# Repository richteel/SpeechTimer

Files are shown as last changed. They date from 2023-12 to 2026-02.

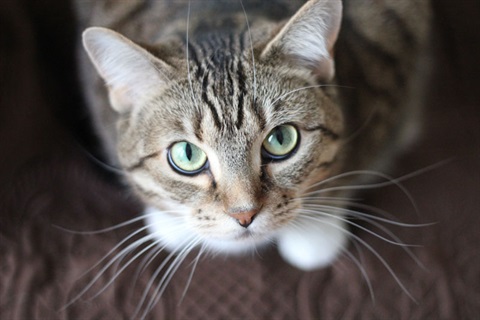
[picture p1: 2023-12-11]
CircuitPython/wwwroot/images/cat.jpg

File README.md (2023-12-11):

# SpeechTimer
Clock/Timer for Speeches

# Folder Structure #

There are several folders in this project. Below is a brief description of each one.

- **CircuitPython:** An early prototype with a web interface. It works but is unstable due to memory fragmentation. It is no longer being developed. It is kept here if anyone using Python wants to use it or improve upon it.
- **Documentation:** Some documentation used during development along with user guide and other miscellaneous materials.
	- **Speech Timer - Developer Guide.docx:** Not much here at the moment. *(Just a placeholder)*
	- **Speech Timer - User Guide.docx:** Very basic user guide showing how to use the remote.
- **PCB:** Eagle project with schematic and PCB design. This is for the development version, which incorporates two Raspberry Pi Pico boards. A regular Raspberry Pi Pico as a Picoprobe and a Raspberry Pi Pico W as the micro-controller running the show.
- **SD Card:** Contents for the micro SD card.
- **SpeechTimer:** The Arduino Sketch C++ project written using the Arduino IDE. Currently everything seems to be working, but the Web Interface has not been created yet.

# Parts List #

- Raspberry Pi Pico
	- Quantity: 1
	- Note: Used as Picoprobe for programming and debugging
- Raspberry Pi Pico W
	- Quantity: 1
- 5mm Neopixels (Through hole)
	- Quantity: 58
	- Source(s): [Adafruit](https://www.adafruit.com/product/1938) / [AliExpress](https://www.aliexpress.us/item/3256804752897372.html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)
- SD Card Breakout
	- Quantity: 1
	- Source(s): [Adafruit](https://www.adafruit.com/product/4682)
- Monochrome 0.96" 128x54 OLED Display
	- Quantity: 1
	- Source(s): [Adafruit](https://www.adafruit.com/product/326) / [Amazon](https://www.amazon.com/gp/product/B08VNRH5HR/ref=ppx_yo_dt_b_search_asin_image?ie=UTF8&th=1)
- Remote
	- Quantity: 1
	- Source(s): [Amazon](https://www.amazon.com/gp/product/B0C7BPJYH1/ref=ppx_yo_dt_b_search_asin_image?ie=UTF8&psc=1)
- 2.54mm (0.1") JST Connectors (3, 4, & 6 position)
	- Quantity: 1 each 3-position, 4-position, and 6-position
	- Source(s): [Amazon](https://www.amazon.com/gp/product/B015Y6JOUG/ref=ppx_yo_dt_b_search_asin_image?ie=UTF8&psc=1) / [AliExpress](https://www.aliexpress.us/item/2251832778234720.html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)
- 2.54mm (0.1") Female Headers
	- Quantity: 5 (4 20-position, 1 9-position)
	- Source(s): [Adafruit](https://www.adafruit.com/product/598)
- 2.54mm (0.1") Male Headers
	- Quantity: 5 (4 20-position, 1 9-position)
	- Source(s): [Adafruit](https://www.adafruit.com/product/2671)
- Momentary Push Button Switch (N.O.) 6mm slim
	- Quantity: 2
	- Source(s): [Adafruit](https://www.adafruit.com/product/1489)
- IR Receiver TSOP38238
	- Quantity: 1
	- Source(s): [Adafruit](https://www.adafruit.com/product/157) / [AliExpress](https://www.aliexpress.us/item/2251832658861424.html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)
- IR LED 5mm
	- Quantity: 1
	- Source(s): [Adafruit](https://www.adafruit.com/product/388)
- Red LED 3mm
	- Quantity: 1
	- Source(s): [Adafruit](https://www.adafruit.com/product/777)
- CdS Photoresistor
	- Quantity: 1
	- Source(s): [Adafruit](https://www.adafruit.com/product/161)

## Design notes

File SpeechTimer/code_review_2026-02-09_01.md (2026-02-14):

# Code Review - SpeechTimer Project
**Date:** February 9, 2026  
**Reviewer:** GitHub Copilot  
**Platform:** Raspberry Pi Pico W  

---

## **Overall Architecture** ✅

### Strengths:
- Well-organized modular structure with clear separation of concerns (Clk_Output, Clk_Rtc, Clk_Wifi, Clk_SdCard, Clk_Remote)
- Good use of FreeRTOS tasks for concurrent operations
- Appropriate use of queues for inter-task communication

### Concerns:
- Tight coupling between classes through direct pointer passing in constructors
- Global objects could make testing and reusability difficult

---

## **Memory & Resource Management** ⚠️

### Critical Issues:

#### 1. Buffer Overflows in `config.h`
**Location:** Lines 1-26  
**Issue:** Excessively large buffer allocations
- `char ssid[256]` and `char pass[256]` are too large for embedded systems
- `char hostname[256]` is also oversized
- These consume 768 bytes per NetworkInfo struct

**Recommendation:**
```cpp
struct NetworkInfo {
  char ssid[32];   // Changed from 256
  char pass[64];   // Changed from 256
};

struct Config {
  char hostname[32];  // Changed from 256
  char timezone[64];  // Changed from 256
  NetworkInfo networks[NETWORKINFOARRAYSIZE];
  TimerInfo timers[TIMERARRAYSIZE];
};
```

#### 2. String Buffer Risks in `Clk_Rtc.cpp`
**Location:** Line 84  
**Issue:** Unbounded stack allocation
```cpp
char responseBuffer[charCount + 1];  // Could overflow stack
```

**Recommendation:**
```cpp
constexpr size_t MAX_RESPONSE_SIZE = 2048;
if (charCount > MAX_RESPONSE_SIZE) {
    charCount = MAX_RESPONSE_SIZE;
}
char responseBuffer[MAX_RESPONSE_SIZE];
int c = _clock_Wifi->wifiClient.read(responseBuffer, charCount);
```

#### 3. Memory Leaks Potential in `Clk_Rtc.cpp`
**Location:** Lines 186-203 (deserializeInternetTime)  
**Issue:** Storing raw pointers to temporary JSON document data
```cpp
_lastInternetTime.abbreviation = doc["abbreviation"];  // Dangling pointer!
_lastInternetTime.client_ip = doc["client_ip"];
```

**Recommendation:** Change `InternetTimeStruct` to store actual strings:
```cpp
struct InternetTimeStruct {
  char abbreviation[8];        // Changed from const char*
  char client_ip[16];          // Changed from const char*
  char datetime[64];           // Changed from const char*
  int day_of_week;
  int day_of_year;
  bool dst;
  char dst_from[64];           // Changed from const char*
  int dst_offset;
  char dst_until[64];          // Changed from const char*
  int raw_offset;
  char timezone[64];           // Changed from const char*
  long unixtime;
  char utc_datetime[64];       // Changed from const char*
  char utc_offset[8];          // Changed from const char*
  int week_number;
};
```

Then use `strlcpy()` in deserializeInternetTime:
```cpp
strlcpy(_lastInternetTime.abbreviation, doc["abbreviation"] | "", 
        sizeof(_lastInternetTime.abbreviation));
```

---

## **Concurrency & Thread Safety** ⚠️

### Issues:

#### 1. Inconsistent Mutex Usage in `SpeechTimer.ino`
**Issue:** `rtc_mutex` is created but never used

**Locations where RTC is accessed without protection:**
- Line 210: `clockRtc.getTimeString(timeStr)` in `debugMessage()`
- Line 366: `clockRtc.getTimeString(currentTime)` in `checkWiFi()`
- Line 405: `clockRtc.getTimeString(currentTime)` in `clockUpdate()`

**Recommendation:**
```cpp
void debugMessage(const char *message, const char *logfile = "", 
                  DebugLevels debug_level = DebugLevels::Info) {
  const char *errorlevel = debugLevelName[debug_level];
  if (debug_level < debugLevel) {
    return;
  }

  char timeStr[10] = "--:--";
  
  // Protect RTC access
  if (xSemaphoreTake(rtc_mutex, pdMS_TO_TICKS(100)) == pdTRUE) {
    clockRtc.getTimeString(timeStr);
    xSemaphoreGive(rtc_mutex);
  }
  
  char msgBuffer[512];
  sprintf(msgBuffer, "%s\t%s\t%s %s\t%d\t%d\t%d", timeStr, errorlevel, 
          FILE_NAME, message, xPortGetCoreID(), rp2040.getFreeHeap(), 
          uxTaskGetStackHighWaterMark(NULL));
  // ... rest of function
}
```

#### 2. Race Conditions
**Issue:** Shared variables accessed without synchronization

**Vulnerable Variables:**
- `configLoadMillis` and `last_configLoadMillis` (lines 149, 337-346)
- `last_clockMode` (line 161, 467-471)
- `last_ipaddress` (line 144, 349-355)
- `last_WiFiMode` (line 145, 358-362)

**Recommendation:** Create additional mutexes or use atomic operations:
```cpp
static SemaphoreHandle_t config_mutex;
static SemaphoreHandle_t display_mutex;

// In setup():
config_mutex = xSemaphoreCreateMutex();
display_mutex = xSemaphoreCreateMutex();

// When accessing:
if (xSemaphoreTake(config_mutex, pdMS_TO_TICKS(100)) == pdTRUE) {
    if (configLoadMillis != last_configLoadMillis) {
        // ... handle config change
    }
    xSemaphoreGive(config_mutex);
}
```

#### 3. Deadlock Risk in `checkSdCard` Task
**Location:** Lines 269-275  
**Issue:** Doesn't handle mutex acquisition failure gracefully

**Current Code:**
```cpp
if (xSemaphoreTake(sdcard_mutex, 100) == pdTRUE) {
    clockSdCard.writeLogEntry(item.logfile, item.message);
    xSemaphoreGive(sdcard_mutex);
} else {
    Dbg_printf(...);  // Just prints error
    writeToFile = false;
}
```

**Recommendation:** Add retry logic or re-queue the item:
```cpp
const uint8_t MAX_RETRIES = 3;
uint8_t retries = 0;

while (retries < MAX_RETRIES) {
    if (xSemaphoreTake(sdcard_mutex, pdMS_TO_TICKS(100)) == pdTRUE) {
        clockSdCard.writeLogEntry(item.logfile, item.message);
        xSemaphoreGive(sdcard_mutex);
        break;
    }
    retries++;
    vTaskDelay(pdMS_TO_TICKS(50));  // Brief delay before retry
}

if (retries >= MAX_RETRIES) {
    // Re-queue or log failure
    xQueueSendToFront(log_queue, &item, 0);  // Try to preserve message
}
```

---

## **Error Handling** ⚠️

### Issues:

#### 1. Silent Failures in `Clk_Wifi.cpp`
**Location:** Line 76  
**Issue:** `checkConnection()` is empty

```cpp
void Clk_Wifi::checkConnection(int maxRetries, bool fromBegin) {
    // Empty function!
}
```

**Recommendation:** Implement proper connection checking:
```cpp
void Clk_Wifi::checkConnection(int maxRetries, bool fromBegin) {
    if (wifiMode != WIFI_STA) {
        return;  // Only check in station mode
    }
    
    for (int i = 0; i < maxRetries; i++) {
        if (WiFi.status() == WL_CONNECTED) {
            return;
        }
        
        DEBUGV("%s checkConnection - Retry %d/%d\n", 
               FILE_NAME_WIFI, i + 1, maxRetries);
        
        if (wifiMulti.run() == WL_CONNECTED) {
            return;
        }
        
        delay(1000);
    }
    
    // Failed to connect
    DEBUGV("%s checkConnection - Failed after %d retries\n", 
           FILE_NAME_WIFI, maxRetries);
}
```

#### 2. Stack Overflow Risk in `Clk_Wifi.cpp`
**Location:** Lines 54-62  
**Issue:** Recursive call to `begin()` could overflow stack

**Current Code:**
```cpp
if (wifiMulti.run() != WL_CONNECTED) {
    if (_beginLoopCount < 5) {
        DEBUGV(...);
        _beginLoopCount++;
        delay(1000);
        begin(configuration);  // Recursive!
```

**Recommendation:** Use iteration instead:
```cpp
bool Clk_Wifi::begin(Config *configuration) {
    config = configuration;
    apAddedCount = 0;
    _beginLoopCount = 0;
    
    // ... setup code ...
    
    // Replace recursion with loop
    const uint8_t MAX_ATTEMPTS = 5;
    while (_beginLoopCount < MAX_ATTEMPTS) {
        if (wifiMulti.run() == WL_CONNECTED) {
            DEBUGV("%s begin - WiFi connected, SSID: %s\n", 
                   FILE_NAME_WIFI, WiFi.SSID().c_str());
            DEBUGV("%s begin - IP address: %s\n", 
                   FILE_NAME_WIFI, WiFi.localIP().toString().c_str());
            return true;
        }
        
        _beginLoopCount++;
        DEBUGV("%s begin - Attempt %d/%d failed\n", 
               FILE_NAME_WIFI, _beginLoopCount, MAX_ATTEMPTS);
        delay(1000);
    }
    
    DEBUGV("%s begin - Failed to connect after %d attempts\n", 
           FILE_NAME_WIFI, MAX_ATTEMPTS);
    return false;
}
```

#### 3. No Timeout Handling in `Clk_Rtc.cpp`
**Location:** Lines 27-47  
**Issue:** Connection could hang despite timeout parameter

**Recommendation:** Add connection timeout:
```cpp
long Clk_Rtc::getInternetTime(long timeoutMs) {
    // ... setup code ...
    
    unsigned long connectStart = millis();
    while (!_clock_Wifi->wifiClient.connect(server, 80)) {
        if (millis() - connectStart > timeoutMs / 2) {
            DEBUGV("[CLK_RTC] Connection timeout\n");
            return 0;
        }
        delay(100);
    }
    
    // ... rest of function ...
}
```

#### 4. Queue Overflow in `SpeechTimer.ino`
**Location:** Line 217  
**Issue:** When log queue is full, message is lost

**Recommendation:** Implement overflow handling:
```cpp
if (xQueueSend(log_queue, (void *)&logEntry, 10) != pdTRUE) {
    // Try to make room by dropping oldest entry
    Log_Entry dummy;
    xQueueReceive(log_queue, &dummy, 0);  // Remove oldest
    
    // Try again
    if (xQueueSend(log_queue, (void *)&logEntry, 0) != pdTRUE) {
        // Still failed, print directly
        Dbg_printf("%s: CRITICAL - Log Queue Full, message lost:\n%s\n", 
                   debugLevelName[DebugLevels::Error], msgBuffer);
    }
}
```

---

## **Code Quality** 📝

### Good Practices:
- Consistent naming conventions
- Helpful comments and documentation
- Good pin documentation in headers
- Clear file structure

### Areas for Improvement:

#### 1. Magic Numbers
**Issue:** Hardcoded values throughout code

**Examples:**
- Stack sizes: `2048` (lines 546-549)
- Delays: `250`, `100`, `10` (throughout)
- Buffer sizes: Various locations

**Recommendation:** Define constants:
```cpp
// Add to Defines.h or new Constants.h
namespace TaskConfig {
    constexpr size_t STACK_SIZE = 2048;
    constexpr TickType_t REMOTE_CHECK_DELAY_MS = 250;
    constexpr TickType_t SDCARD_CHECK_DELAY_MS = 250;
    constexpr TickType_t WIFI_CHECK_DELAY_MS = 250;
    constexpr TickType_t CLOCK_UPDATE_DELAY_MS = 100;
    constexpr uint8_t SETUP_WAIT_DELAY_MS = 10;
}

namespace QueueConfig {
    constexpr uint8_t LOG_QUEUE_LENGTH = 10;
    constexpr uint8_t REMOTE_QUEUE_LENGTH = 5;
}

namespace TimeoutConfig {
    constexpr TickType_t MUTEX_TIMEOUT_MS = 100;
    constexpr TickType_t QUEUE_SEND_TIMEOUT_MS = 10;
    constexpr long INTERNET_TIME_TIMEOUT_MS = 2000;
}
```

#### 2. Deep Nesting in `SpeechTimer.ino`
**Location:** Lines 421-480 (clockUpdate task)  
**Issue:** Complex switch statement with nested logic

**Recommendation:** Extract to state handler functions:
```cpp
void handleTimerDigitInput(char digit) {
    char numberBuffer[10];
    if (clockOutput.clockMode == ClockMode::TimerSetMin) {
        int minVal = clockOutput.timerSetMin();
        sprintf(numberBuffer, "%d%c", minVal, digit);
        minVal = atoi(numberBuffer);
        clockOutput.timerSetMin(minVal);
    } else if (clockOutput.clockMode == ClockMode::TimerSetMax) {
        int maxVal = clockOutput.timerSetMax();
        sprintf(numberBuffer, "%d%c", maxVal, digit);
        maxVal = atoi(numberBuffer);
        clockOutput.timerSetMax(maxVal);
    }
}

void handleNavigationInput(char direction) {
    if (direction == 'L' && clockOutput.clockMode == ClockMode::TimerSetMax) {
        clockOutput.clockMode = ClockMode::TimerSetMin;
    } else if (direction == 'R' && clockOutput.clockMode == ClockMode::TimerSetMin) {
        clockOutput.clockMode = ClockMode::TimerSetMax;
    }
}

void handleOkButton() {
    switch (clockOutput.clockMode) {
        case ClockMode::TimerReady:
            clockOutput.clockMode = ClockMode::TimerRun;
            break;
        case ClockMode::TimerRun:
            clockOutput.clockMode = ClockMode::TimerStop;
            break;
        case ClockMode::TimerStop:
            clockOutput.clockMode = ClockMode::TimerReady;
            break;
    }
}

// Then in clockUpdate:
while (xQueueReceive(remote_queue, (void *)&item, 0) == pdTRUE) {
    if (item >= '0' && item <= '9') {
        handleTimerDigitInput(item);
    } else if (item == 'L' || item == 'R') {
        handleNavigationInput(item);
    } else if (item == 'K') {
        handleOkButton();
    } else if (item == '*') {
        clockOutput.clockMode = ClockMode::Clock;
    } else if (item == '#') {
        handleHashButton();
    }
}
```

#### 3. Debug Macros in `DbgPrint.h`
**Location:** Lines 1-32  
**Current Implementation:** Good, but could be cleaner

**Recommendation:** Single abstraction layer:
```cpp
#ifndef DBGPRINT
#define DBGPRINT

#define DEBUG 1          // SET TO 0 TO REMOVE TRACES
#define USE_PICOPROBE 1  // Set to 1 if using Picoprobe

#if DEBUG
    #if USE_PICOPROBE
        #define DEBUG_SERIAL Serial1
    #else
        #define DEBUG_SERIAL Serial
    #endif
    
    #define Dbg_begin(...) DEBUG_SERIAL.begin(__VA_ARGS__)
    #define Dbg_end(...) DEBUG_SERIAL.end(__VA_ARGS__)
    #define Dbg_print(...) DEBUG_SERIAL.print(__VA_ARGS__)
    #define Dbg_println(...) DEBUG_SERIAL.println(__VA_ARGS__)
    #define Dbg_printf(...) DEBUG_SERIAL.printf(__VA_ARGS__)
    #define Dbg_write(...) DEBUG_SERIAL.write(__VA_ARGS__)
#else
    #define Dbg_begin(...)
    #define Dbg_end(...)
    #define Dbg_print(...)
    #define Dbg_println(...)
    #define Dbg_printf(...)
    #define Dbg_write(...)
#endif

#endif  // DBGPRINT
```

#### 4. Long Functions
**Issue:** Several functions exceed 50 lines

**Functions to refactor:**
- `getInternetTime()` in Clk_Rtc.cpp (116 lines)
- `checkSdCard()` in SpeechTimer.ino (61 lines)
- `checkWiFi()` in SpeechTimer.ino (71 lines)
- `clockUpdate()` in SpeechTimer.ino (97 lines)

**Recommendation:** Apply Single Responsibility Principle—each function should do one thing.

---

## **Potential Bugs** 🐛

### 1. Reference Bug in `Clk_SdCard.cpp`
**Location:** Line 38  
**Severity:** HIGH - Data not being cleared

**Current Code:**
```cpp
void Clk_SdCard::clearConfig() {
  sdCardConfig.hostname[0] = '\0';
  sdCardConfig.timezone[0] = '\0';

  for (NetworkInfo ni : sdCardConfig.networks) {  // BUG: Copies by value!
    ni.ssid[0] = '\0';  // Modifies copy, not original
    ni.pass[0] = '\0';
  }

  for (TimerInfo ti : sdCardConfig.timers) {  // BUG: Copies by value!
    ti.min = 0;
    ti.max = 0;
    ti.manual = true;
  }
}
```

**Fix:** Use references:
```cpp
void Clk_SdCard::clearConfig() {
  sdCardConfig.hostname[0] = '\0';
  sdCardConfig.timezone[0] = '\0';

  for (NetworkInfo& ni : sdCardConfig.networks) {  // Fixed: Use reference
    ni.ssid[0] = '\0';
    ni.pass[0] = '\0';
  }

  for (TimerInfo& ti : sdCardConfig.timers) {  // Fixed: Use reference
    ti.min = 0;
    ti.max = 0;
    ti.manual = true;
  }
}
```

### 2. Dangling Pointers in `Clk_Rtc.cpp`
**Location:** Lines 186-203  
**Severity:** CRITICAL - Will cause crashes

**Issue:** `_lastInternetTime` stores `const char*` pointers to temporary JSON document that's destroyed when function returns.

**Fix:** See Memory Management section above for complete solution.

### 3. Boolean Conversion Error in `SpeechTimer.ino`
**Location:** Line 523  
**Severity:** MEDIUM - Undefined behavior

**Current Code:**
```cpp
while (DEBUG && !(Serial || Serial1)) {
    delay(1);  // wait for serial port to connect.
}
```

**Issue:** `Serial` and `Serial1` are objects. The `||` operator doesn't work as intended.

**Fix:**
```cpp
while (DEBUG && !Serial && !Serial1) {
    delay(1);  // wait for serial port to connect.
}
```

Or better, be explicit:
```cpp
#if DEBUG
    #if USE_PICOPROBE
        while (!Serial1) { delay(1); }
    #else
        while (!Serial) { delay(1); }
    #endif
#endif
```

### 4. Potential NULL Dereference
**Location:** Throughout codebase  
**Issue:** Pointers passed in constructors never checked for NULL

**Example in Clk_Output.cpp:**
```cpp
Clk_Output::Clk_Output(Clk_SdCard *sdcard) {
  _sdcard = sdcard;  // Never checked if NULL!
}
```

**Recommendation:** Add validation:
```cpp
Clk_Output::Clk_Output(Clk_SdCard *sdcard) {
  if (sdcard == nullptr) {
    DEBUGV("[CLK_OUTPUT] ERROR: sdcard pointer is NULL\n");
    // Handle error appropriately
  }
  _sdcard = sdcard;
}
```

---

## **Security Concerns** 🔒

### 1. WiFi Credentials in Plaintext
**Location:** config.h, Clk_SdCard.cpp  
**Issue:** Passwords stored unencrypted on SD card

**Current Risk:**
- Anyone with physical access can read WiFi passwords
- SD card can be removed and read on any computer

**Recommendations:**
1. **Short term:** Add warning in documentation
2. **Medium term:** Implement basic XOR obfuscation
3. **Long term:** Use proper encryption (AES)

**Example XOR obfuscation:**
```cpp
constexpr uint8_t OBFUSCATION_KEY = 0xA5;

void obfuscateString(char* str, size_t len) {
    for (size_t i = 0; i < len && str[i] != '\0'; i++) {
        str[i] ^= OBFUSCATION_KEY;
    }
}

// Obfuscate before saving, deobfuscate after loading
```

### 2. No Input Validation
**Location:** Clk_SdCard.cpp (loadConfig)  
**Issue:** JSON parsing lacks validation

**Risks:**
- Malicious config files could cause buffer overflows
- Oversized JSON could exhaust memory
- Invalid data could cause unexpected behavior

**Recommendation:** Add validation:
```cpp
bool Clk_SdCard::loadConfig(const char *fileFullName) {
    // ... existing code ...
    
    File f = readFile(sdCardConfigFullName);
    if (!f) {
        return false;
    }
    
    // Check file size
    size_t fileSize = f.size();
    constexpr size_t MAX_CONFIG_SIZE = 8192;  // 8KB limit
    if (fileSize > MAX_CONFIG_SIZE) {
        DEBUGV("%s loadConfig - Config file too large: %d bytes\n", 
               FILE_NAME_CARD, fileSize);
        f.close();
        return false;
    }
    
    // ... rest of parsing ...
    
    // Validate loaded data
    if (strlen(sdCardConfig.hostname) == 0) {
        strlcpy(sdCardConfig.hostname, "speechtimer", 
                sizeof(sdCardConfig.hostname));
    }
    
    // Validate network entries
    for (auto& ni : sdCardConfig.networks) {
        if (strlen(ni.ssid) > 32) {
            DEBUGV("%s loadConfig - SSID too long, truncating\n", 
                   FILE_NAME_CARD);
            ni.ssid[32] = '\0';
        }
    }
    
    return true;
}
```

### 3. No Authentication for Web Interface
**Location:** Project documentation mentions web interface  
**Issue:** No code visible for authentication

**Recommendation:** If web interface is implemented:
- Add basic authentication (username/password)
- Use HTTPS when possible
- Implement session management
- Add CSRF protection

---

## **Performance Optimizations** ⚡

### 1. Excessive String Operations
**Location:** Throughout, especially in debug messages  
**Issue:** Many `sprintf()` calls create strings that may not be used

**Example from Line 210:**
```cpp
sprintf(msgBuffer, "%s\t%s\t%s %s\t%d\t%d\t%d", timeStr, errorlevel, 
        FILE_NAME, message, xPortGetCoreID(), rp2040.getFreeHeap(), 
        uxTaskGetStackHighWaterMark(NULL));
```

**Recommendation:** Only format when actually writing to file:
```cpp
void debugMessage(const char *message, const char *logfile = "", 
                  DebugLevels debug_level = DebugLevels::Info) {
  if (debug_level < debugLevel) {
    return;  // Early exit before any work
  }

  Log_Entry logEntry;
  logEntry.message[0] = '\0';  // Start empty
  logEntry.debug_level = debug_level;
  logEntry.timestamp = millis();
  strlcpy(logEntry.raw_message, message, sizeof(logEntry.raw_message));
  strlcpy(logEntry.logfile, logfile, sizeof(logEntry.logfile));

  // Format only when writing
  xQueueSend(log_queue, (void *)&logEntry, 10);
}
```

### 2. Task Delays
**Current:** All tasks use 250ms delays  
**Issue:** May be suboptimal for responsiveness and power consumption

**Recommendations by task:**
- `checkRemote`: 250ms is reasonable for button debouncing
- `checkSdCard`: Could be 500ms (SD card changes are infrequent)
- `checkWiFi`: Could be 1000ms when connected, 250ms when connecting
- `clockUpdate`: 100ms is good for display updates

**Example adaptive delay:**
```cpp
void checkWiFi() {
    while (1) {
        bool isConnected = clockWifi.hasIpAddress();
        
        // ... task work ...
        
        // Adaptive delay
        TickType_t delay = isConnected ? 
                          pdMS_TO_TICKS(1000) :  // Slow when stable
                          pdMS_TO_TICKS(250);     // Fast when connecting
        vTaskDelay(delay);
    }
}
```

### 3. Light Sensor Rolling Average
**Location:** Clk_Output.cpp  
**Issue:** Could optimize calculation

**Current approach:** Likely recalculates average each time (need to see full implementation)

**Recommendation:** Use sliding window with cached sum:
```cpp
class Clk_Output {
private:
    int _lightValues[10];
    int _lightValuesLen = 10;
    int _lightValueIndex = 0;
    int _lightValueSum = 0;  // Cache the sum

public:
    void updateLightValue(int newValue) {
        // Subtract old value from sum
        _lightValueSum -= _lightValues[_lightValueIndex];
        
        // Add new value
        _lightValues[_lightValueIndex] = newValue;
        _lightValueSum += newValue;
        
        // Move to next position
        _lightValueIndex = (_lightValueIndex + 1) % _lightValuesLen;
    }
    
    int getAverageLightValue() {
        return _lightValueSum / _lightValuesLen;
    }
};
```

### 4. Reduce Queue Overhead
**Issue:** Log queue processes many debug messages

**Recommendation:** Add filtering at source:
```cpp
// Only send important messages to queue when debug level is high
if (debug_level >= debugLevel || strlen(logfile) > 0) {
    xQueueSend(log_queue, (void *)&logEntry, 10);
} else {
    // Skip queueing for unimportant messages
    return;
}
```

---

## **Testing Recommendations** 🧪

### Unit Testing
The code would benefit from unit tests for:
1. **Time conversion functions** (unixToDatetime_t)
2. **JSON parsing** (deserializeInternetTime, loadConfig)
3. **State transitions** (Clock mode changes)
4. **String operations** (All the sprintf calls)

### Integration Testing
1. **WiFi reconnection** after network failure
2. **SD card hot-swap** handling
3. **RTC time synchronization** accuracy
4. **Timer accuracy** over long periods

### Stress Testing
1. **Queue overflow scenarios**
2. **Rapid button presses** on remote
3. **Long running stability** (24+ hours)
4. **Memory leak detection** over time

---

## **Documentation Improvements** 📚

### 1. Add Function Documentation
**Recommendation:** Use Doxygen-style comments

**Example:**
```cpp
/**
 * @brief Retrieves current time from internet time API
 * 
 * Connects to worldtimeapi.org and parses the JSON response to set
 * the system time. Uses timezone from config if available.
 * 
 * @param timeoutMs Maximum time to wait for response in milliseconds
 * @return Unix timestamp if successful, 0 on failure
 * 
 * @note This function is blocking and should only be called from
 *       tasks with sufficient stack space.
 * @warning Requires active WiFi connection with valid IP address
 */
long Clk_Rtc::getInternetTime(long timeoutMs = 2000);
```

### 2. State Machine Documentation
**Add diagram for Clock Mode transitions:**

```
Clock Mode State Machine:
┌─────────┐    #      ┌──────────────┐    K     ┌──────────┐
│  Clock  │──────────>│ TimerReady   │────────>│ TimerRun │
└─────────┘           └──────────────┘         └──────────┘
     ^      *              ^  ^  #                    │  K
     │                     │  │                       v
     └─────────────────────┘  └─────────────── ┌──────────┐
                                                │TimerStop │
                                    K           └──────────┘
                                    └──────────>│          │
                                                 └──────────┘
```

### 3. Add README Section
Create sections for:
- **Quick Start Guide**
- **Configuration File Format**
- **Remote Control Button Mapping**
- **Troubleshooting Common Issues**
- **Memory Requirements**
- **Known Limitations**

---

## **Priority Implementation Plan** 📋

### HIGH Priority (Fix Immediately) 🔴
1. ✅ **Fix clearConfig() reference bug** - Clk_SdCard.cpp line 38
2. ✅ **Fix dangling pointers** - Change InternetTimeStruct to use char arrays
3. ✅ **Fix Serial boolean check** - SpeechTimer.ino line 523
4. ✅ **Add mutex protection for RTC** - Throughout SpeechTimer.ino
5. ✅ **Add bounds check for responseBuffer** - Clk_Rtc.cpp line 84

### MEDIUM Priority (Improve Stability) 🟡
6. Implement proper WiFi checkConnection()
7. Convert recursive begin() to iterative
8. Add connection timeout in getInternetTime()
9. Reduce buffer sizes in config.h
10. Add null pointer checks in constructors
11. Implement queue overflow handling
12. Add retry logic for SD card writes

### LOW Priority (Code Quality) 🟢
13. Extract magic numbers to constants
14. Refactor long functions into smaller pieces
15. Create state handler functions for remote input
16. Simplify debug macro implementation
17. Add Doxygen documentation
18. Implement light sensor optimization
19. Add adaptive task delays
20. Create unit tests

### OPTIONAL (Future Enhancements) ⚪
21. Implement password encryption
22. Add input validation for config files
23. Add web interface authentication
24. Implement watchdog timer
25. Add dependency injection for testability
26. Create comprehensive integration tests

---

## **Estimated Impact** 📊

### Memory Savings (High Priority Fixes)
- Reduce config.h buffers: **~6KB saved**
- Fix response buffer: **Stack overflow prevented**
- Fix InternetTimeStruct: **Memory safety improved**

### Stability Improvements
- Mutex protection: **Prevents race conditions**
- Bounds checking: **Prevents crashes**
- Error handling: **Graceful degradation**

### Code Quality
- Constants: **Better maintainability**
- Function refactoring: **Easier to debug**
- Documentation: **Faster onboarding**

---

## **Conclusion** 📝

This is a **well-structured embedded project** with good use of FreeRTOS primitives. The main concerns are:

1. **Thread safety** - Several shared variables lack synchronization
2. **Memory management** - Oversized buffers and dangling pointers
3. **Error handling** - Some failure modes are not handled

The **high-priority fixes** are critical for stability and should be addressed before deployment. The **medium-priority items** will significantly improve reliability. The **low-priority improvements** will make the codebase more maintainable.

**Overall Assessment:** B+ (Good architecture, needs safety improvements)

---

## **Additional Resources** 🔗

### Recommended Reading:
1. [FreeRTOS Mutual Exclusion](https://www.freertos.org/a00113.html)
2. [Embedded C Coding Standard](https://barrgroup.com/embedded-systems/books/embedded-c-coding-standard)
3. [Arduino Memory Guide](https://docs.arduino.cc/learn/programming/memory-guide)
4. [Raspberry Pi Pico SDK Documentation](https://www.raspberrypi.com/documentation/pico-sdk/)

### Tools to Consider:
1. **Static Analysis:** PVS-Studio, Cppcheck
2. **Memory Analysis:** Valgrind (if testing on desktop)
3. **Code Coverage:** lcov with unit tests
4. **Documentation:** Doxygen

---

**End of Code Review**

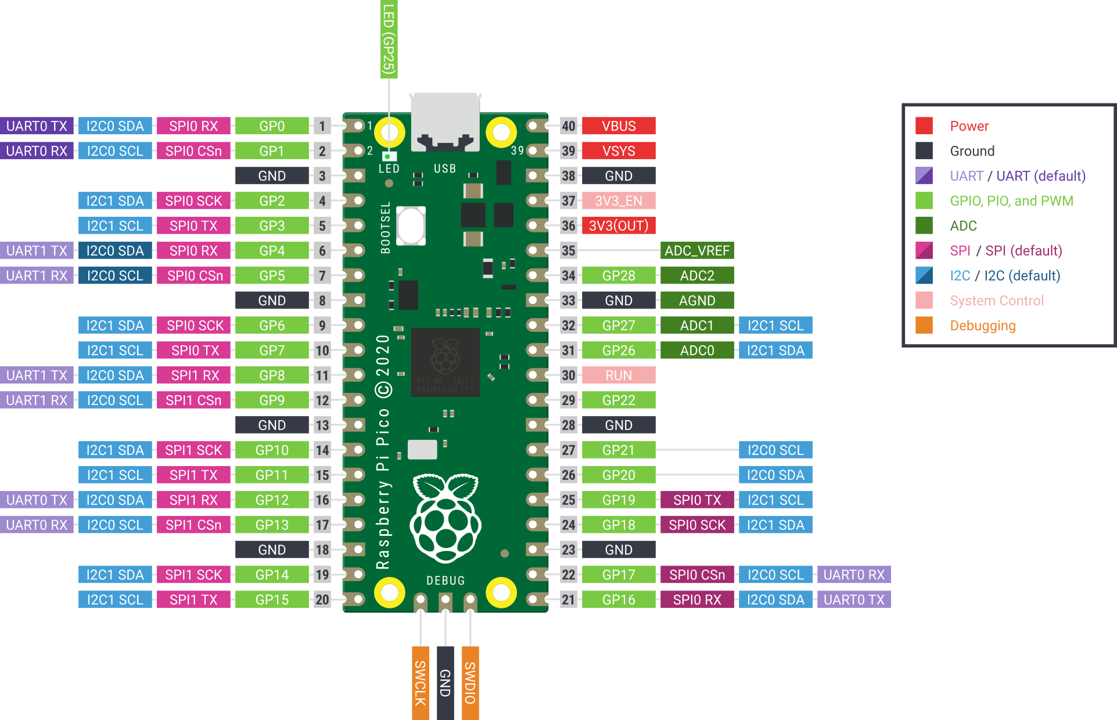
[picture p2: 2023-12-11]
Documentation/Images/pico-pinout.png

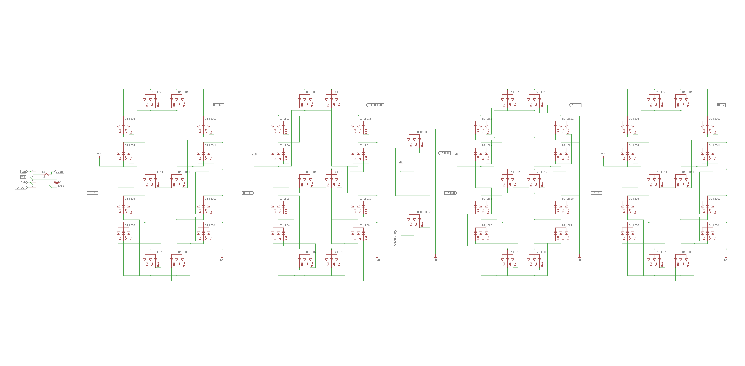
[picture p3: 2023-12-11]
Documentation/Images/Schematic_Eagle (LED Board).png

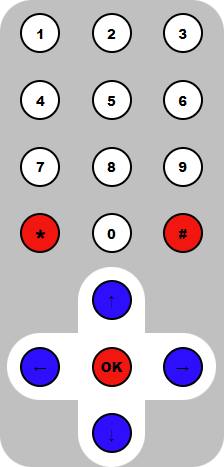
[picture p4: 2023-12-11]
Documentation/Images/Remote0.png

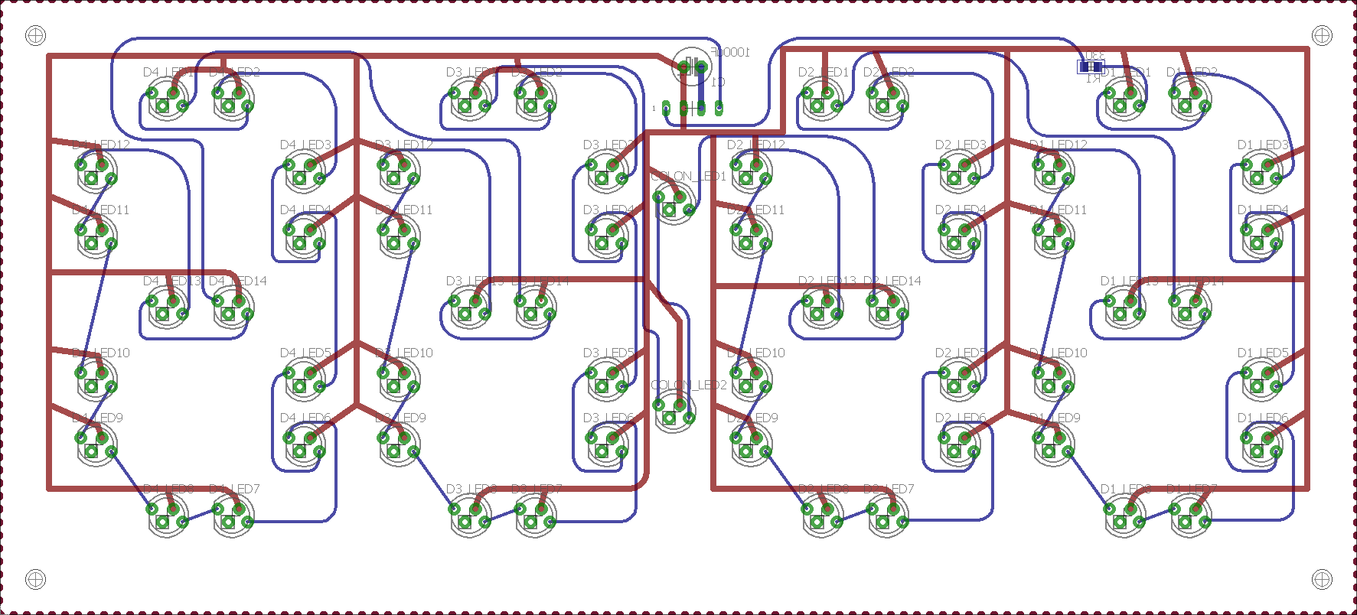
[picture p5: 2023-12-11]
Documentation/Images/PCB_Eagle (LED Board).png

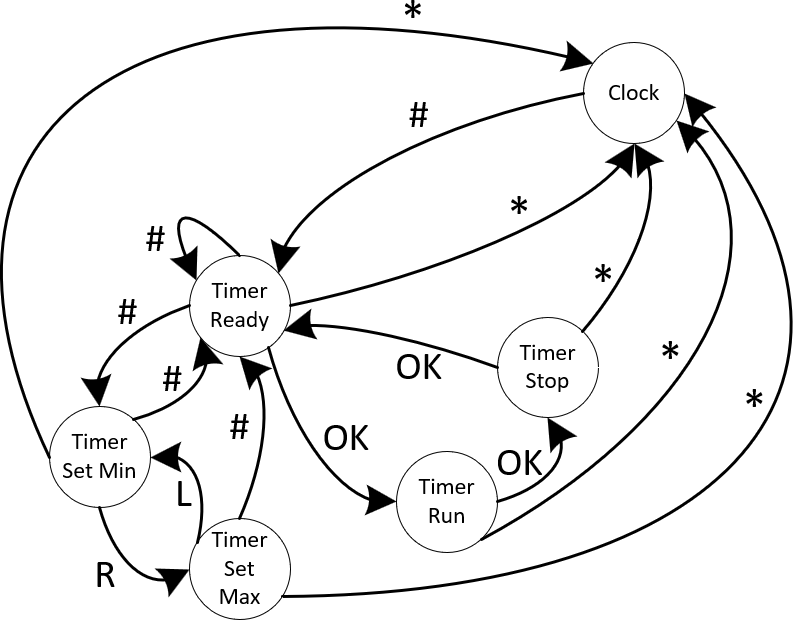
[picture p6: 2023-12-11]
Documentation/Images/StateDiagram.png

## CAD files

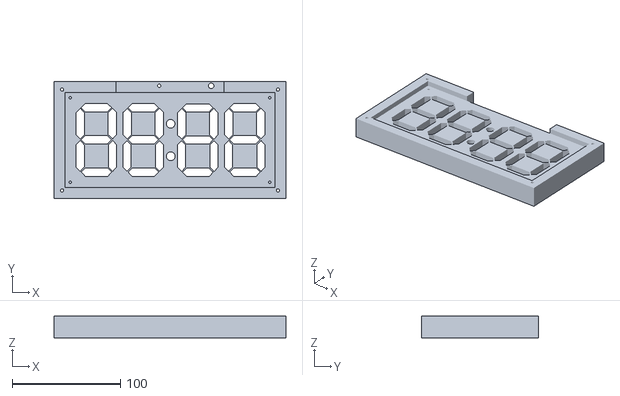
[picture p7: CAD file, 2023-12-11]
Case/3D Case/Case.stl
214.0 x 108.0 x 20.0

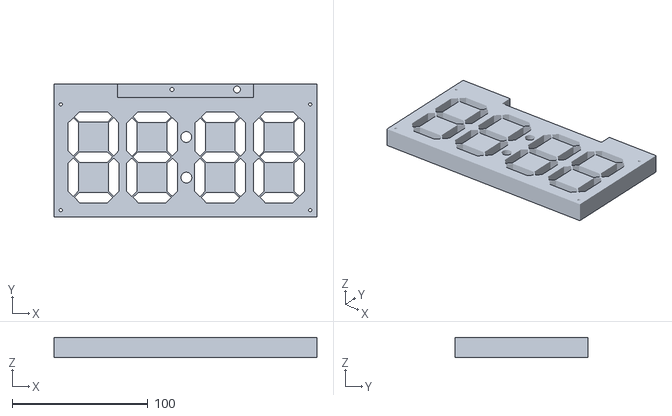
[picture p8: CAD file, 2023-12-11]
Case/3D Case/Case2.stl
194.0 x 98.0 x 15.0

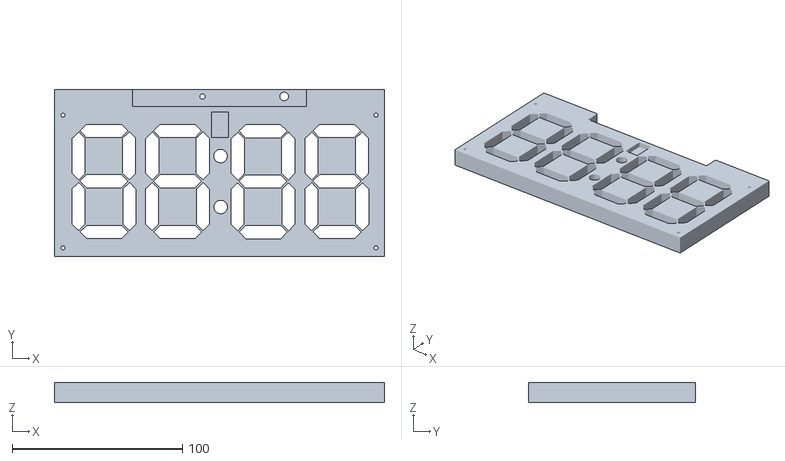
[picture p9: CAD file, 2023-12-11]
Case/3D Case/Case3.stl
194.0 x 98.0 x 12.0

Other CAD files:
Case/3D Case/Case.skp
Case/3D Case/Case2.skp
Case/3D Case/Case3.skp

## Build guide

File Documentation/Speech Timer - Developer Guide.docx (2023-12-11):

- Speech Timer
  - Min Time
  - Max Time
  - Button: Start & Stop
- Clock
  - Color
    - Red
    - Green
    - Blue
  - Button: Update Color
- Information
  - Data Displayed
    - Server Directory
    - CPU Temperature
    - CPU Frequency
    - Last Reset Reason
    - UID
    - Voltage
    - Memory Total
    - Memory Free
    - Memory Used
  - Button: Refresh
- Test
  - Button: Test
- Remote
  - 1:
  - 2:
  - 3:
  - 4:
  - 5:
  - 6:
  - 7:
  - 8:
  - 9:
  - 0:
  - *:
  - #:
  - Up:
  - Down:
  - Left:
  - Right:
  - OK:

Remote

Button | IR Information | Function | Notes
0 | Command is 25 Protocol=NEC Address=0x0 Command=0x19
1 | Command is 69 Protocol=NEC Address=0x0 Command=0x45
2 | Command is 70 Protocol=NEC Address=0x0 Command=0x46
3 | Command is 71 Protocol=NEC Address=0x0 Command=0x47
4 | Command is 68 Protocol=NEC Address=0x0 Command=0x44
5 | Command is 64 Protocol=NEC Address=0x0 Command=0x40
6 | Command is 67 Protocol=NEC Address=0x0 Command=0x43
7 | Command is 7 Protocol=NEC Address=0x0 Command=0x7
8 | Command is 21 Protocol=NEC Address=0x0 Command=0x15
9 | Command is 9 Protocol=NEC Address=0x0 Command=0x9
* | Command is 22 Protocol=NEC Address=0x0 Command=0x16
# | Command is 13 Protocol=NEC Address=0x0 Command=0xD

Up | Command is 24 Protocol=NEC Address=0x0 Command=0x18
Down | Command is 82 Protocol=NEC Address=0x0 Command=0x52
Left | Command is 8 Protocol=NEC Address=0x0 Command=0x8
Right | Command is 90 Protocol=NEC Address=0x0 Command=0x5A
OK | Command is 28 Protocol=NEC Address=0x0 Command=0x1C


# Timer

Steps

1. Press the “#” key to enter timer mode. The clock will show the first preset time with <min>:<max>. As an example, if the first timer preset has a min of 5 and a max of 7 minutes, the clock will display 05:07.

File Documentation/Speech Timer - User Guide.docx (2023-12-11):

# Speech Timer

User Manual

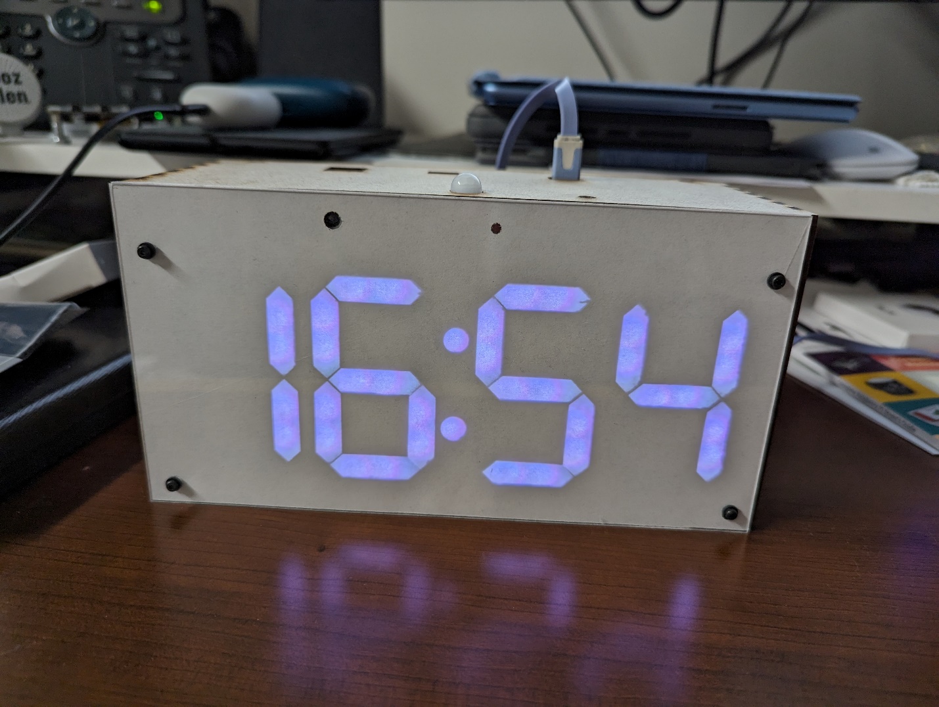
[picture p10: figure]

Updated: 9 December 2023

# Introduction

There are two methods for interacting with the timer. One method is the remote, which is available, regardless of internet connectivity. The second method is the web interface, which is only available when the timer is connected to an internet connection. A third method may be introduced in the future to provide a Bluetooth connection with control through a mobile app.

# Using the Remote

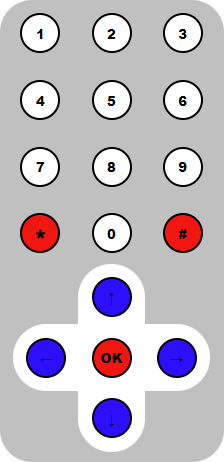
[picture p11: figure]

## Showing the Clock

Pressing the asterisk (*) button will return to displaying the clock. If any timers are running, they will be stopped. The color of the clock will return to the selected color for the clock, which is white by default.

## Entering Timer Mode

Pressing the hash, a.k.a. pound or number, (#) button will enter the timer mode. Pressing it repeatedly will cycle through the various timers.

- First press
  - Default speech time of 5 to 7 minutes.
  - The display will show “05:07”.
- Second press
  - Default table topics time of 1 to 2 minutes.
  - The display will show “01:02”.
- Third press
  - Default evaluation time of 2 to 3 minutes.
  - The display will show “02:03”.
- Fourth press
  - Manual time mode
  - Display will show “00:00” or the previous set time with the digits on the left flashing.
- Fifth press
  - Manual time will be set, and the timer is ready to be started.

### Manual time mode

The manual time mode allows setting the timer for other min and max times with the minimum time on the left and the maximum time on the right of the colon. If the times entered have the maximum less than the minimum time, the times will be reversed so that the maximum time is greater than the minimum time.

The left and right buttons move between the minimum and maximum time settings. When the minimum time is selected, the digit(s) on the left will be flashing and when the maximum time is selected, the digit(s) on the right will be flashing. The time is entered from the numbers on the keypad. The maximum value that may be entered is 99 (1 hour, 39 minutes). If an error is made, reenter the correct value.

The up and down buttons may be used to increase or decrease the value by one.

Once the correct values are entered, press the hash button to enter timer mode. The digits will stop flashing, indicating that the timer is ready.

### Timing a speech or event

Once the desired timer is selected, press the OK button to start the timer. The timer will start counting from zero. The colors will change to green once the minimum time is reached, yellow when the midpoint between the minimum and maximum time is reached, and red when the maximum time is reached.

Pressing the OK button, a second time stops the timer and time remains on the display showing the minutes and seconds.

Pressing the OK button, a third time resets the timer so that it is ready to time another speaker or event. The display will show the minimum and maximum times for the timer.

OK Button function

- First press – Start the timer.
- Second press – Stop the timer.
- Third press – Reset the timer.

### Display colors

As the timer is counting from zero to the minimum time, the display will be white. When the counter reaches the minimum time, the color of the display will change to green and will remain green until the timer reaches the midpoint between the minimum and maximum times. When the midpoint is reached, the color will change to yellow until the timer reaches the maximum time. When the timer reaches the maximum time, the display color will turn red.

If the minimum time and the maximum time are the same, the display color will change from white to red, when the time is reached. This is non-standard behavior as there should be at least one minute difference between the minimum and maximum times.

# State Diagram


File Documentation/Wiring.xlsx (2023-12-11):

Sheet: Sheet1
Segment | X | Y | W | H
Separation |  |  | 2 | 2
a | 9.55 | 158.484 | 75.242 | 15.1
b | 79.242 | 88.792 | 15.1 | 75.242
c | 79.242 | 9.55 | 15.1 | 75.242
d | 9.55 | 0 | 75.242 | 15.1
e | 0 | 9.55 | 15.1 | 75.242
f | 0 | 88.792 | 15.1 | 75.242
g | 9.55 | 79.242 | 75.242 | 15.1

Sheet: Sheet1 (2)
 |  |  |  |  | Hole - Power
Segment | X | Y | W | H | X | Y
Hole |  |  | 3.1 | 10.1
Separation |  |  | 2 | 2
a | 7.56875 | 99.492 | 40.746 | 11.1375 | 22.607375 | 53.76475
b | 44.746 | 62.31475 | 11.1375 | 40.746 | 22.89175 | 46.480375
c | 44.746 | 17.56875 | 11.1375 | 40.746 | 22.89175 | 24.107375
d | 7.56875 | 10 | 40.746 | 11.1375 | 22.607375 | 9.01875
e | 10 | 17.56875 | 11.1375 | 40.746 | 5.51875 | 24.107375
f | 10 | 62.31475 | 11.1375 | 40.746 | 5.51875 | 46.480375
g | 17.56875 | 54.746 | 40.746 | 11.1375 | 27.607375 | 31.39175

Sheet: Sheet1 (3)
 |  |  |  |  | Hole - Power
Segment | X | Y | W | H | X | Y
Hole |  |  | 3.1 | 10.1
Separation |  |  | 1.528 | 1.527
a | 17.097 | 97.596 | 40.748 | 11.137 | 35.921 | 98.1145
b | 53.804 | 60.8935 | 11.138 | 40.744 | 54.323 | 79.7155
c | 53.804 | 17.0955 | 11.138 | 40.744 | 54.323 | 35.9175
d | 17.097 | 10 | 40.748 | 11.137 | 35.921 | 10.5185
e | 10 | 17.0955 | 11.138 | 40.744 | 10.519 | 35.9175
f | 10 | 60.8935 | 11.138 | 40.744 | 10.519 | 79.7155
g | 17.097 | 53.798 | 40.748 | 11.137 | 35.921 | 54.3165

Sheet: Sheet1 (4)
 |  |  |  |  | Hole - Power
Segment | X | Y | W | H | X | Y
Hole |  |  | 3.1 | 10.1
Separation |  |  | 1.528 | 1.527
a | 17.045 | 97.388 | 40.748 | 11.137 | 35.869 | 97.9065
b | 53.699 | 60.737 | 11.138 | 40.744 | 54.218 | 79.559
c | 53.699 | 17.044 | 11.138 | 40.744 | 54.218 | 35.866
d | 17.044 | 10 | 40.748 | 11.137 | 35.868 | 10.5185
e | 10 | 17.044 | 11.138 | 40.744 | 10.519 | 35.866
f | 10 | 60.737 | 11.138 | 40.744 | 10.519 | 79.559
g | 17.044 | 53.694 | 40.748 | 11.137 | 35.868 | 54.2125
Segment | X | Y | W | H | X | Y
Segments | 10 | 10 | 54.837 | 98.525
Holes | 14.05 | 14.016 | 53.799 | 97.488 | 4.05 | 4.016
Min-ones | 72.699 | 10 | 54.837 | 98.525 | 76.749 | 14.016
Sec-tens | 146.462 | 10 | 54.837 | 98.525 | 150.512 | 14.016
Sec-ones | 209.161 | 10 | 54.837 | 98.525 | 213.211 | 14.016

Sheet: Scaled
Description | W | H
Original 40x15mm | 344.342 | 133.584
10" | 254 | 98.53673383
In inches | 10 | 3.87939897
 | 20 | 20
 | 274 | 118.5367338

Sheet: Points
Point | X | Y
A | 0.05 | 0.05 | B | C
B | 0.05 | 15.05
C | 40.05 | 15.05 | A | D
D | 40.05 | 0.05
AA | -7.5 | 7.55
DD | 47.6 | 7.55

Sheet: Pico Pinouts
Pin | GPIO | Function | Device | Device Pin | Pin | GPIO | Function | Device | Device Pin
1 | 0 | GP0 |  |  | 40 |  | VBUS | Neopixels | PWR
2 | 1 | GP1 |  |  | 39 |  | VSYS
3 |  | GND |  |  | 38 |  | GND | SD Card & OLED | GND
4 | 2 | GP2 |  |  | 37 |  | 3V3_EN
5 | 3 | GP3 |  |  | 36 |  | 3V3(OUT) | SD Card & OLED | 3V
6 | 4 | GP4 | OLED | SDA | 35 |  | ADC_VREF
7 | 5 | GP5 | OLED | SCK | 34 | 28 | GP28 | Neopixels | Data in
8 |  | GND |  |  | 33 |  | GND | Neopixels | GND
9 | 6 | GP6 |  |  | 32 | 27 | GP27
10 | 7 | GP7 |  |  | 31 | 26 | GP26 | Remote | IR_IN
11 | 8 | GP8 |  |  | 30 |  | RUN
12 | 9 | GP9 |  |  | 29 | 22 | GP22
13 |  | GND |  |  | 28 |  | GND
14 | 10 | GP10 |  |  | 27 | 21 | GP21
15 | 11 | GP11 |  |  | 26 | 20 | GP20 | SD Card | CD
16 | 12 | GP12 |  |  | 25 | 19 | GP19 | SD Card | MOSI
17 | 13 | GP13 |  |  | 24 | 18 | GP18 | SD Card | SCK
18 |  | GND |  |  | 23 |  | GND
19 | 14 | GP14 |  |  | 22 | 17 | GP17 | SD Card | CS
20 | 15 | GP15 |  |  | 21 | 16 | GP16 | SD Card | MISO

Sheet: Pico Pinouts (2)
Device Pin | Device | Function | GPIO | Pin | Pin | GPIO | Function | Device | Device Pin
SDA | OLED | GP0 | 0 | 1 | 40 |  | VBUS | Neopixels | PWR
SCK | OLED | GP1 | 1 | 2 | 39 |  | VSYS
 |  | GND |  | 3 | 38 |  | GND | SD Card & OLED | GND
 |  | GP2 | 2 | 4 | 37 |  | 3V3_EN
 |  | GP3 | 3 | 5 | 36 |  | 3V3(OUT) | SD Card & OLED | 3V
 |  | GP4 | 4 | 6 | 35 |  | ADC_VREF
 |  | GP5 | 5 | 7 | 34 | 28 | GP28 | Neopixels | Data in
 |  | GND |  | 8 | 33 |  | GND | Neopixels | GND
 |  | GP6 | 6 | 9 | 32 | 27 | GP27
 |  | GP7 | 7 | 10 | 31 | 26 | GP26
MISO | SD Card | GP8 | 8 | 11 | 30 |  | RUN
CS | SD Card | GP9 | 9 | 12 | 29 | 22 | GP22
 |  | GND |  | 13 | 28 |  | GND
SCK | SD Card | GP10 | 10 | 14 | 27 | 21 | GP21
MOSI | SD Card | GP11 | 11 | 15 | 26 | 20 | GP20
CD | SD Card | GP12 | 12 | 16 | 25 | 19 | GP19
 |  | GP13 | 13 | 17 | 24 | 18 | GP18
 |  | GND |  | 18 | 23 |  | GND
 |  | GP14 | 14 | 19 | 22 | 17 | GP17
 |  | GP15 | 15 | 20 | 21 | 16 | GP16

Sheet: Debug Sizes
All sizes are in bytes
 | Flash | RAM
Max | 2093056 | 262144
Debug | Program storage space | Global variables | Program storage space | Global variables
1 | 343516 | 72140 | 16.412% | 27.519%
0 | 342348 | 72140 | 16.356% | 27.519%
Delta | 1168 | 0 | 0.056% | 0.000%

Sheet: Sheet2
Char | a | b | c | d | e | f | g | binary ga | binary ag | hex ga | hex ag
0 | 1 | 1 | 1 | 1 | 1 | 1 | 0 | 0111111 | 1111110 | 0x3F | 0x7E
1 | 0 | 1 | 1 | 0 | 0 | 0 | 0 | 0000110 | 0110000 | 0x06 | 0x30
2 | 1 | 1 | 0 | 1 | 1 | 0 | 1 | 1011011 | 1101101 | 0x5B | 0x6D
3 | 1 | 1 | 1 | 1 | 0 | 0 | 1 | 1001111 | 1111001 | 0x4F | 0x79
4 | 0 | 1 | 1 | 0 | 0 | 1 | 1 | 1100110 | 0110011 | 0x66 | 0x33
5 | 1 | 0 | 1 | 1 | 0 | 1 | 1 | 1101101 | 1011011 | 0x6D | 0x5B
6 | 1 | 0 | 1 | 1 | 1 | 1 | 1 | 1111101 | 1011111 | 0x7D | 0x5F
7 | 1 | 1 | 1 | 0 | 0 | 0 | 0 | 0000111 | 1110000 | 0x07 | 0x70
8 | 1 | 1 | 1 | 1 | 1 | 1 | 1 | 1111111 | 1111111 | 0x7F | 0x7F
9 | 1 | 1 | 1 | 0 | 0 | 1 | 1 | 1100111 | 1110011 | 0x67 | 0x73
 | 0 | 0 | 0 | 0 | 0 | 0 | 0 | 0000000 | 0000000 | 0x00 | 0x00
- | 0 | 0 | 0 | 0 | 0 | 0 | 1 | 1000000 | 0000001 | 0x40 | 0x01

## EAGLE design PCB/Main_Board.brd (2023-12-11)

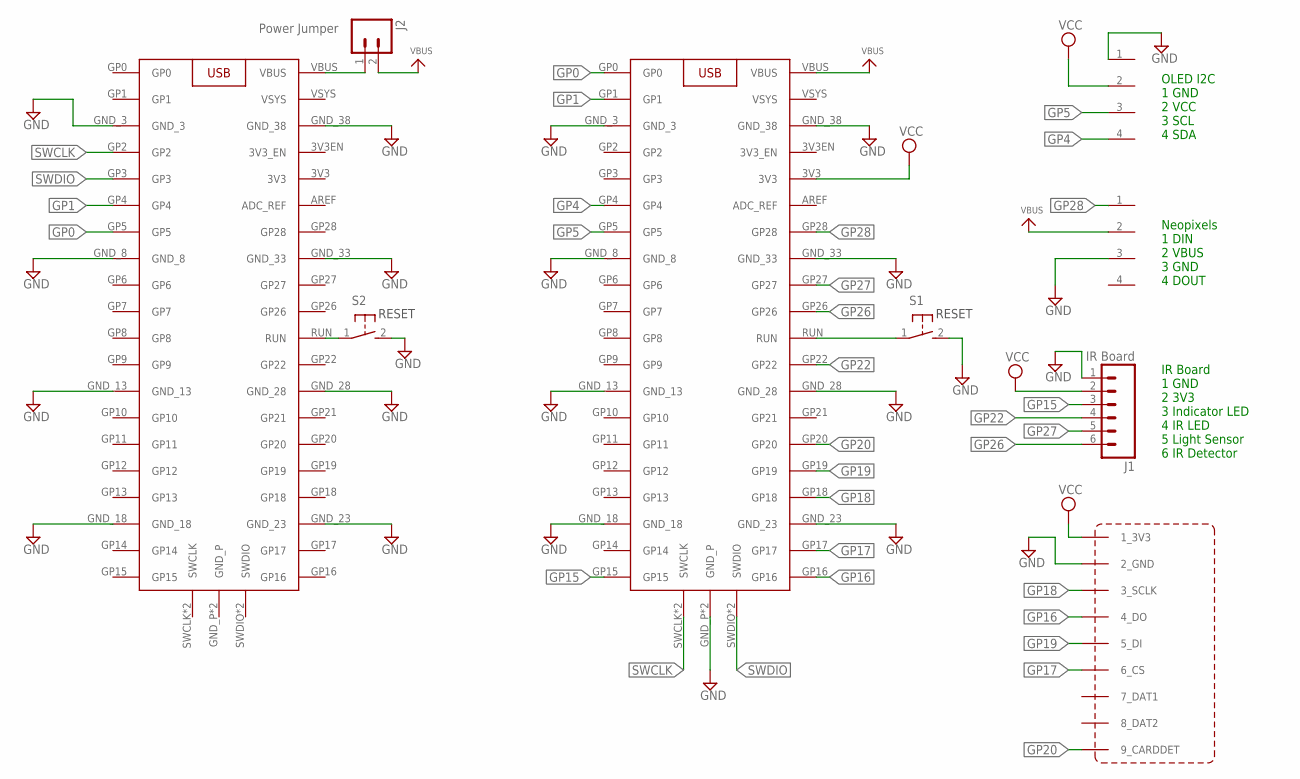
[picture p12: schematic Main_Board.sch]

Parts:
J1: IR Board; 1X06_LONGPADS
J2: Power Jumper; 1X02_LOCK_LONGPADS
S1, S2: RESET; ADAFRUIT_SW_1489
SDCARD2: ADAFRUIT_SDCARD3V3THROUGHHOLE; ADAFRUIT_SDCARD3V3
U$1, U$2: RASPBERRY_PI_PICORASPBERRY_PI_PICO_&_W; RASPBERRY_PI_PICO_N_W
U$3, U$4: HEADER-1X4

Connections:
GND: J1.1, S1.2 (S), S2.2 (S), SDCARD2.2_GND, U$1.GND_3, U$1.GND_8, U$1.GND_13, U$1.GND_18, U$1.GND_23, U$1.GND_28, U$1.GND_33, U$1.GND_38, U$1.GND_P, U$1.GND_P1 (GND_P), U$2.GND_3, U$2.GND_8, U$2.GND_13, U$2.GND_18, U$2.GND_23, U$2.GND_28, U$2.GND_33, U$2.GND_38, U$3.3, U$4.1
GP0: U$1.GP0, U$2.GP5
GP1: U$1.GP1, U$2.GP4
GP4: U$1.GP4, U$4.4
GP5: U$1.GP5, U$4.3
GP15: J1.3, U$1.GP15
GP16: SDCARD2.4_DO, U$1.GP16
GP17: SDCARD2.6_CS, U$1.GP17
GP18: SDCARD2.3_SCLK, U$1.GP18
GP19: SDCARD2.5_DI, U$1.GP19
GP20: SDCARD2.9_CARDDET, U$1.GP20
GP22: J1.4, U$1.GP22
GP26: J1.6, U$1.GP26
GP27: J1.5, U$1.GP27
GP28: U$1.GP28, U$3.1
unnamed: S2.1, U$2.RUN
unnamed: J2.1, U$2.VBUS
unnamed: S1.1, U$1.RUN
SWCLK: U$1.SWCLK, U$1.SWCLK1 (SWCLK), U$2.GP2
SWDIO: U$1.SWDIO, U$1.SWDIO1 (SWDIO), U$2.GP3
VBUS: J2.2, U$1.VBUS, U$3.2
VCC: J1.2, SDCARD2.1_3V3, U$1.3V3, U$4.2

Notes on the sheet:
Neopixels 1 DIN 2 VBUS 3 GND 4 DOUT
OLED I2C 1 GND 2 VCC 3 SCL 4 SDA
IR Board 1 GND 2 3V3 3 Indicator LED 4 IR LED 5 Light Sensor 6 IR Detector

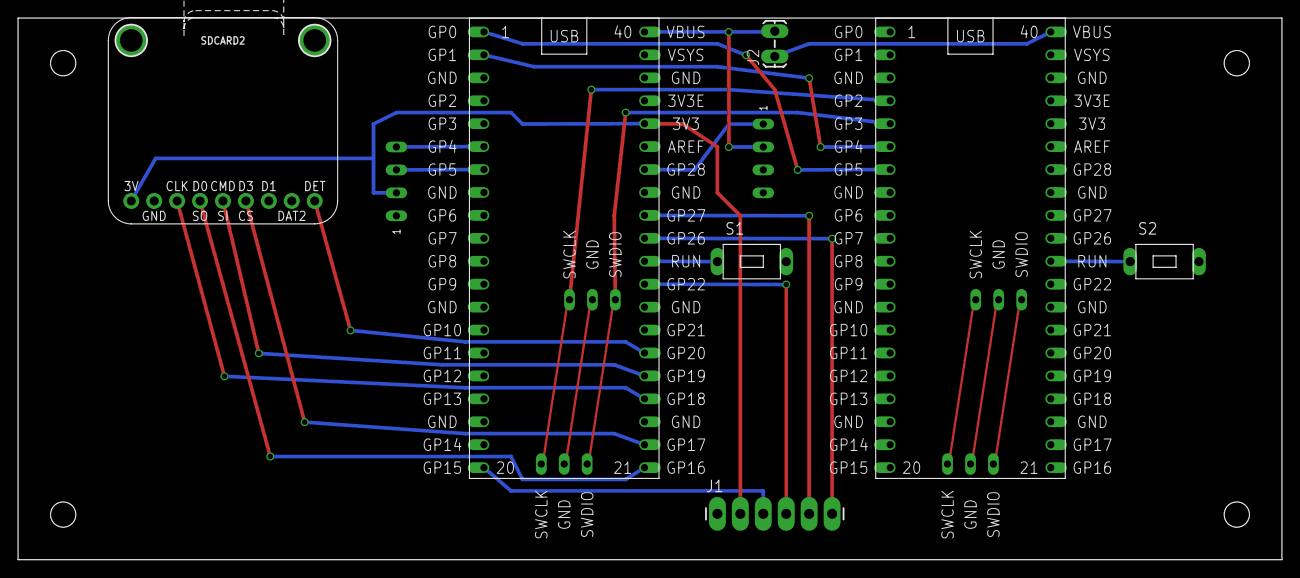
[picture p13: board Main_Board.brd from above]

Board: 2 copper layers, 140.0 x 60.0 mm, 9 parts (0 on the bottom side), 22 nets.

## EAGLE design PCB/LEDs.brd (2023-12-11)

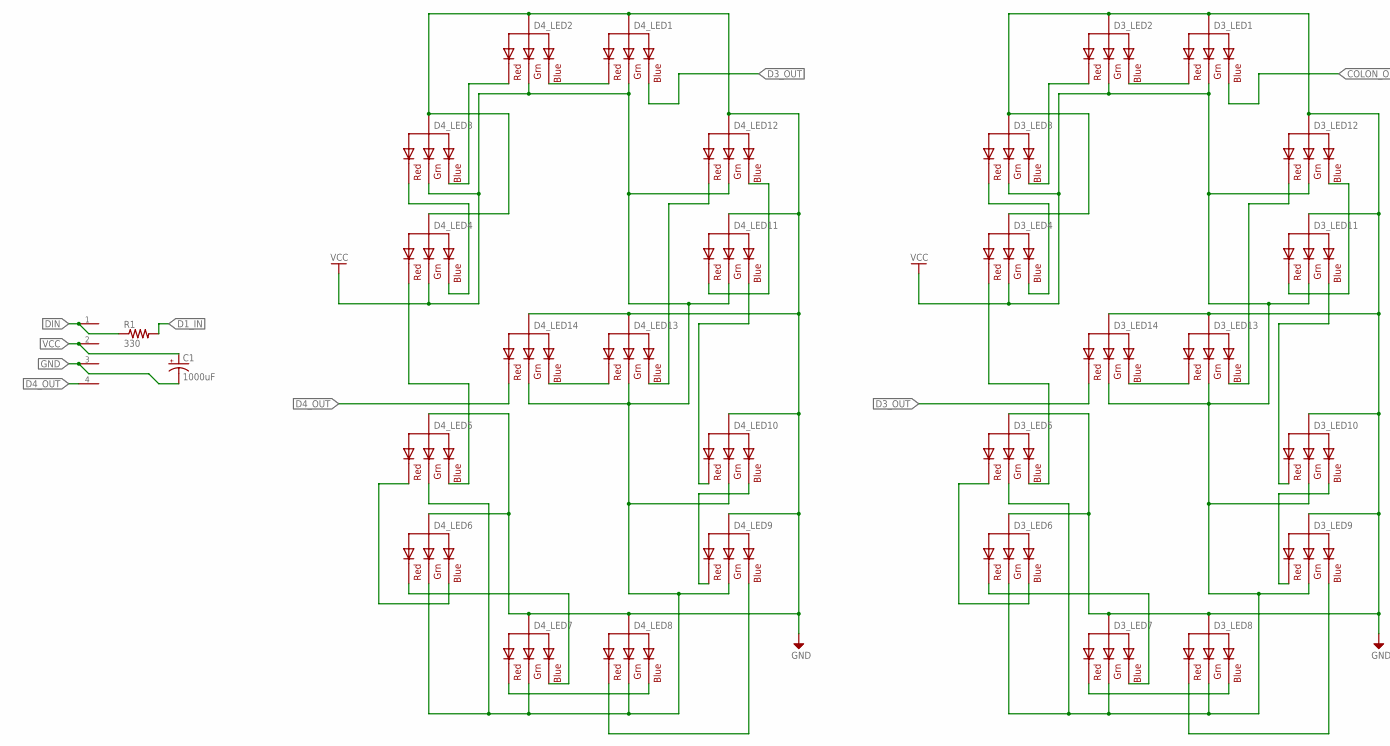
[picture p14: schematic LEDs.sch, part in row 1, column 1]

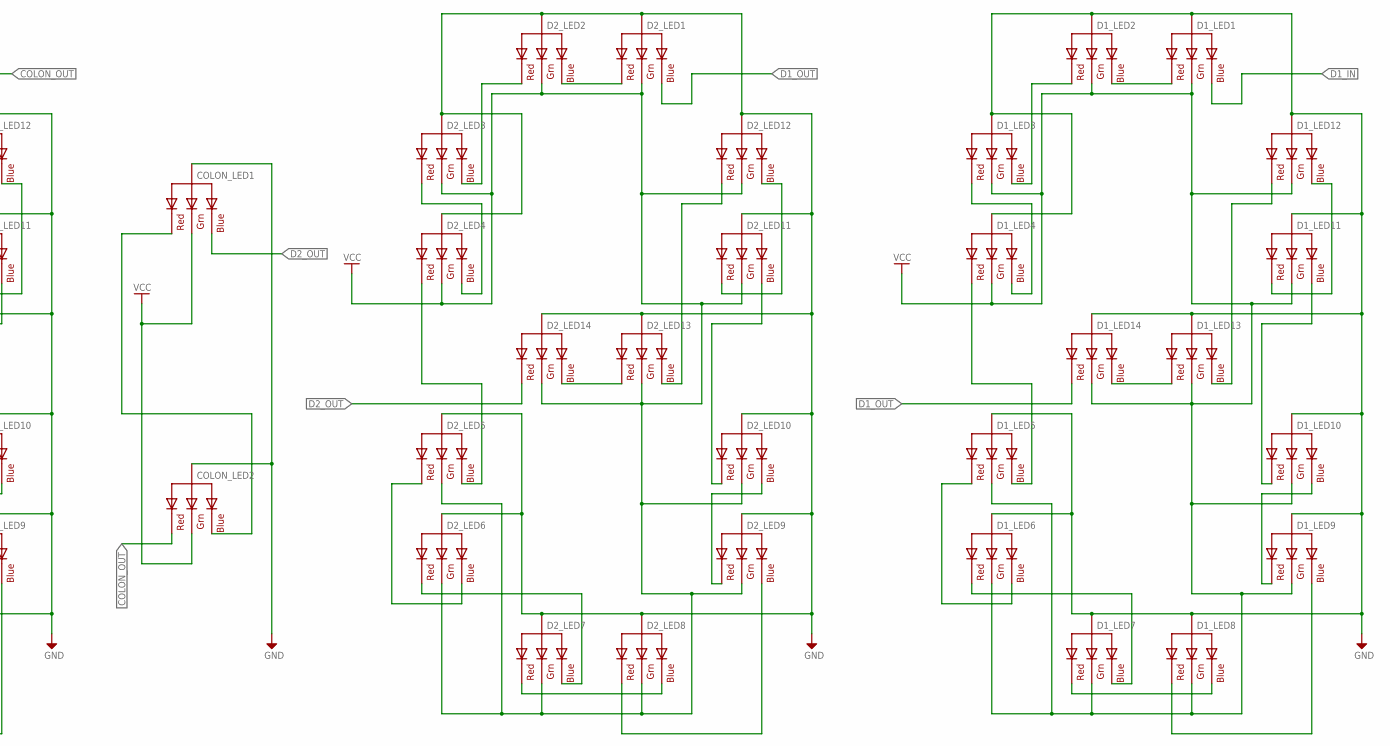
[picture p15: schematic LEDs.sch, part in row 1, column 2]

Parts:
C1: 1000uF; E2,5-6
COLON_LED1, COLON_LED2: RGBLED_CA-5MM; LED5MMRGB
D1_LED1, D1_LED2, D1_LED3, D1_LED4, D1_LED5, D1_LED6, D1_LED7, D1_LED8, D1_LED9, D1_LED10, D1_LED11, D1_LED12, D1_LED13, D1_LED14, D2_LED1, D2_LED2, D2_LED3, D2_LED4, D2_LED5, D2_LED6, D2_LED7, D2_LED8, D2_LED9, D2_LED10, D2_LED11, D2_LED12, D2_LED13, D2_LED14, D3_LED1, D3_LED2, D3_LED3, D3_LED4, D3_LED5, D3_LED6, D3_LED7, D3_LED8, D3_LED9, D3_LED10, D3_LED11, D3_LED12, D3_LED13, D3_LED14, D4_LED1, D4_LED2, D4_LED3, D4_LED4, D4_LED5, D4_LED6, D4_LED7, D4_LED8, D4_LED9, D4_LED10, D4_LED11, D4_LED12, D4_LED13, D4_LED14: RGBLED_CA-5MM; LED5MMRGB
R1: 330; R0805
U$1: HEADER-1X4

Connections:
COLON_OUT: COLON_LED2.1 (RED), D3_LED1.4 (BLUE)
D1_IN: D1_LED1.4 (BLUE), R1.2
D1_OUT: D1_LED14.1 (RED), D2_LED1.4 (BLUE)
D2_OUT: COLON_LED1.4 (BLUE), D2_LED14.1 (RED)
D3_OUT: D3_LED14.1 (RED), D4_LED1.4 (BLUE)
D4_OUT: D4_LED14.1 (RED), U$1.4
DIN: R1.1, U$1.1
GND: C1.-, COLON_LED1.2 (VCC), COLON_LED2.2 (VCC), D1_LED1.2 (VCC), D1_LED2.2 (VCC), D1_LED3.2 (VCC), D1_LED4.2 (VCC), D1_LED5.2 (VCC), D1_LED6.2 (VCC), D1_LED7.2 (VCC), D1_LED8.2 (VCC), D1_LED9.2 (VCC), D1_LED10.2 (VCC), D1_LED11.2 (VCC), D1_LED12.2 (VCC), D1_LED13.2 (VCC), D1_LED14.2 (VCC), D2_LED1.2 (VCC), D2_LED2.2 (VCC), D2_LED3.2 (VCC), D2_LED4.2 (VCC), D2_LED5.2 (VCC), D2_LED6.2 (VCC), D2_LED7.2 (VCC), D2_LED8.2 (VCC), D2_LED9.2 (VCC), D2_LED10.2 (VCC), D2_LED11.2 (VCC), D2_LED12.2 (VCC), D2_LED13.2 (VCC), D2_LED14.2 (VCC), D3_LED1.2 (VCC), D3_LED2.2 (VCC), D3_LED3.2 (VCC), D3_LED4.2 (VCC), D3_LED5.2 (VCC), D3_LED6.2 (VCC), D3_LED7.2 (VCC), D3_LED8.2 (VCC), D3_LED9.2 (VCC), D3_LED10.2 (VCC), D3_LED11.2 (VCC), D3_LED12.2 (VCC), D3_LED13.2 (VCC), D3_LED14.2 (VCC), D4_LED1.2 (VCC), D4_LED2.2 (VCC), D4_LED3.2 (VCC), D4_LED4.2 (VCC), D4_LED5.2 (VCC), D4_LED6.2 (VCC), D4_LED7.2 (VCC), D4_LED8.2 (VCC), D4_LED9.2 (VCC), D4_LED10.2 (VCC), D4_LED11.2 (VCC), D4_LED12.2 (VCC), D4_LED13.2 (VCC), D4_LED14.2 (VCC), U$1.3
unnamed: D1_LED1.1 (RED), D1_LED2.4 (BLUE)
unnamed: D1_LED2.1 (RED), D1_LED3.4 (BLUE)
unnamed: D1_LED3.1 (RED), D1_LED4.4 (BLUE)
unnamed: D1_LED4.1 (RED), D1_LED5.4 (BLUE)
unnamed: D1_LED5.1 (RED), D1_LED6.4 (BLUE)
unnamed: D1_LED6.1 (RED), D1_LED7.4 (BLUE)
unnamed: D1_LED7.1 (RED), D1_LED8.4 (BLUE)
unnamed: D1_LED8.1 (RED), D1_LED9.4 (BLUE)
unnamed: D1_LED9.1 (RED), D1_LED10.4 (BLUE)
unnamed: D1_LED10.1 (RED), D1_LED11.4 (BLUE)
unnamed: D1_LED11.1 (RED), D1_LED12.4 (BLUE)
unnamed: D1_LED12.1 (RED), D1_LED13.4 (BLUE)
unnamed: D1_LED13.1 (RED), D1_LED14.4 (BLUE)
unnamed: D2_LED1.1 (RED), D2_LED2.4 (BLUE)
unnamed: D2_LED2.1 (RED), D2_LED3.4 (BLUE)
unnamed: D2_LED3.1 (RED), D2_LED4.4 (BLUE)
unnamed: D2_LED4.1 (RED), D2_LED5.4 (BLUE)
unnamed: D2_LED5.1 (RED), D2_LED6.4 (BLUE)
unnamed: D2_LED6.1 (RED), D2_LED7.4 (BLUE)
unnamed: D2_LED7.1 (RED), D2_LED8.4 (BLUE)
unnamed: D2_LED8.1 (RED), D2_LED9.4 (BLUE)
unnamed: D2_LED9.1 (RED), D2_LED10.4 (BLUE)
unnamed: D2_LED10.1 (RED), D2_LED11.4 (BLUE)
unnamed: D2_LED11.1 (RED), D2_LED12.4 (BLUE)
unnamed: D2_LED12.1 (RED), D2_LED13.4 (BLUE)
unnamed: D2_LED13.1 (RED), D2_LED14.4 (BLUE)
unnamed: D3_LED1.1 (RED), D3_LED2.4 (BLUE)
unnamed: D3_LED2.1 (RED), D3_LED3.4 (BLUE)
unnamed: D3_LED3.1 (RED), D3_LED4.4 (BLUE)
unnamed: D3_LED4.1 (RED), D3_LED5.4 (BLUE)
unnamed: D3_LED5.1 (RED), D3_LED6.4 (BLUE)
unnamed: D3_LED6.1 (RED), D3_LED7.4 (BLUE)
unnamed: D3_LED7.1 (RED), D3_LED8.4 (BLUE)
unnamed: D3_LED8.1 (RED), D3_LED9.4 (BLUE)
unnamed: D3_LED9.1 (RED), D3_LED10.4 (BLUE)
unnamed: D3_LED10.1 (RED), D3_LED11.4 (BLUE)
unnamed: D3_LED11.1 (RED), D3_LED12.4 (BLUE)
unnamed: D3_LED12.1 (RED), D3_LED13.4 (BLUE)
unnamed: D3_LED13.1 (RED), D3_LED14.4 (BLUE)
unnamed: D4_LED1.1 (RED), D4_LED2.4 (BLUE)
unnamed: D4_LED2.1 (RED), D4_LED3.4 (BLUE)
unnamed: D4_LED3.1 (RED), D4_LED4.4 (BLUE)
unnamed: D4_LED4.1 (RED), D4_LED5.4 (BLUE)
unnamed: D4_LED5.1 (RED), D4_LED6.4 (BLUE)
unnamed: D4_LED6.1 (RED), D4_LED7.4 (BLUE)
unnamed: D4_LED7.1 (RED), D4_LED8.4 (BLUE)
unnamed: D4_LED8.1 (RED), D4_LED9.4 (BLUE)
unnamed: D4_LED9.1 (RED), D4_LED10.4 (BLUE)
unnamed: D4_LED10.1 (RED), D4_LED11.4 (BLUE)
unnamed: D4_LED11.1 (RED), D4_LED12.4 (BLUE)
unnamed: D4_LED12.1 (RED), D4_LED13.4 (BLUE)
unnamed: D4_LED13.1 (RED), D4_LED14.4 (BLUE)
unnamed: COLON_LED1.1 (RED), COLON_LED2.4 (BLUE)
VCC: C1.+, COLON_LED1.3 (GREEN), COLON_LED2.3 (GREEN), D1_LED1.3 (GREEN), D1_LED2.3 (GREEN), D1_LED3.3 (GREEN), D1_LED4.3 (GREEN), D1_LED5.3 (GREEN), D1_LED6.3 (GREEN), D1_LED7.3 (GREEN), D1_LED8.3 (GREEN), D1_LED9.3 (GREEN), D1_LED10.3 (GREEN), D1_LED11.3 (GREEN), D1_LED12.3 (GREEN), D1_LED13.3 (GREEN), D1_LED14.3 (GREEN), D2_LED1.3 (GREEN), D2_LED2.3 (GREEN), D2_LED3.3 (GREEN), D2_LED4.3 (GREEN), D2_LED5.3 (GREEN), D2_LED6.3 (GREEN), D2_LED7.3 (GREEN), D2_LED8.3 (GREEN), D2_LED9.3 (GREEN), D2_LED10.3 (GREEN), D2_LED11.3 (GREEN), D2_LED12.3 (GREEN), D2_LED13.3 (GREEN), D2_LED14.3 (GREEN), D3_LED1.3 (GREEN), D3_LED2.3 (GREEN), D3_LED3.3 (GREEN), D3_LED4.3 (GREEN), D3_LED5.3 (GREEN), D3_LED6.3 (GREEN), D3_LED7.3 (GREEN), D3_LED8.3 (GREEN), D3_LED9.3 (GREEN), D3_LED10.3 (GREEN), D3_LED11.3 (GREEN), D3_LED12.3 (GREEN), D3_LED13.3 (GREEN), D3_LED14.3 (GREEN), D4_LED1.3 (GREEN), D4_LED2.3 (GREEN), D4_LED3.3 (GREEN), D4_LED4.3 (GREEN), D4_LED5.3 (GREEN), D4_LED6.3 (GREEN), D4_LED7.3 (GREEN), D4_LED8.3 (GREEN), D4_LED9.3 (GREEN), D4_LED10.3 (GREEN), D4_LED11.3 (GREEN), D4_LED12.3 (GREEN), D4_LED13.3 (GREEN), D4_LED14.3 (GREEN), U$1.2

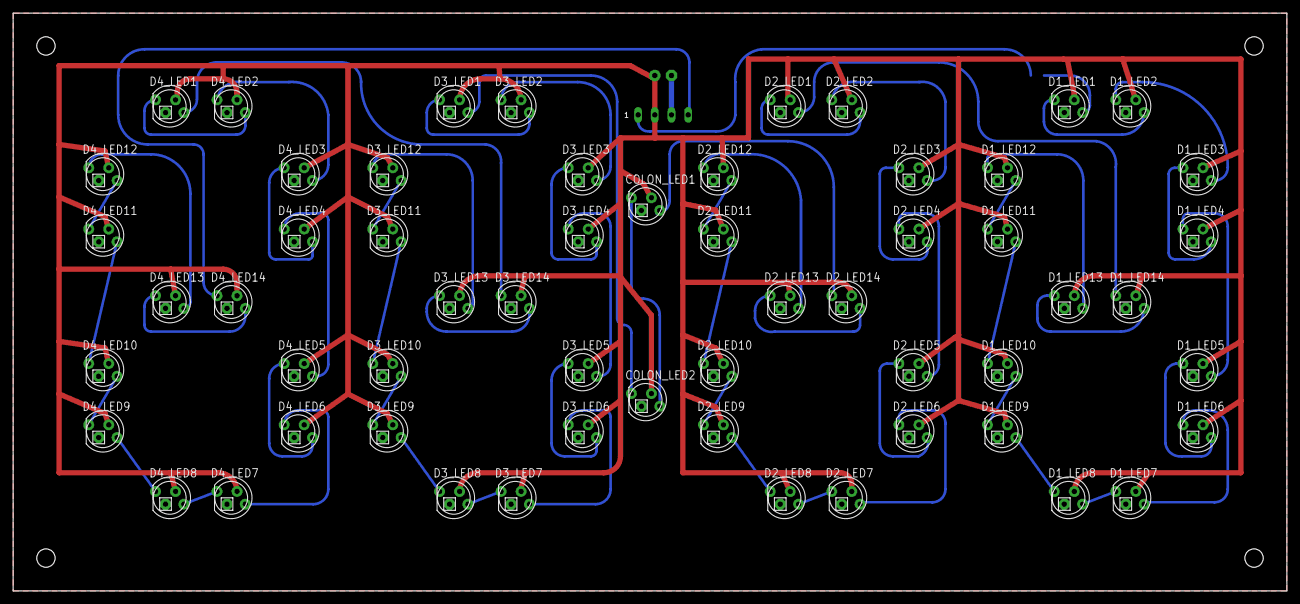
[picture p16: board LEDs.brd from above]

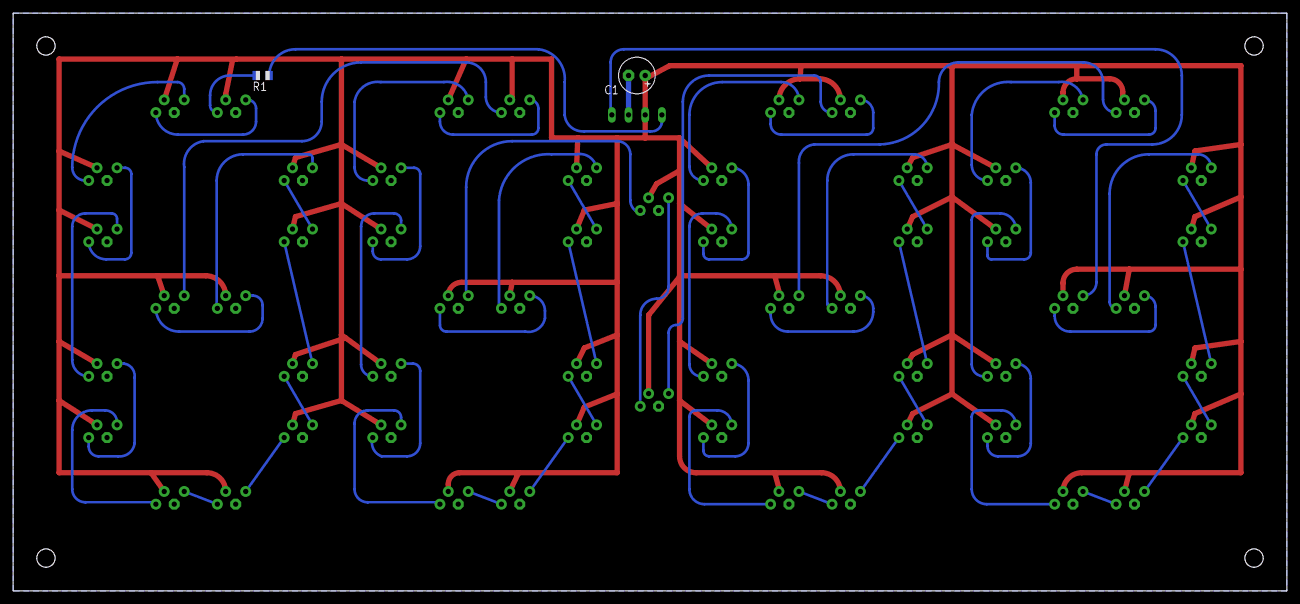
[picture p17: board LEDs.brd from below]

Board: 2 copper layers, 194.0 x 88.0 mm, 61 parts (2 on the bottom side), 62 nets.

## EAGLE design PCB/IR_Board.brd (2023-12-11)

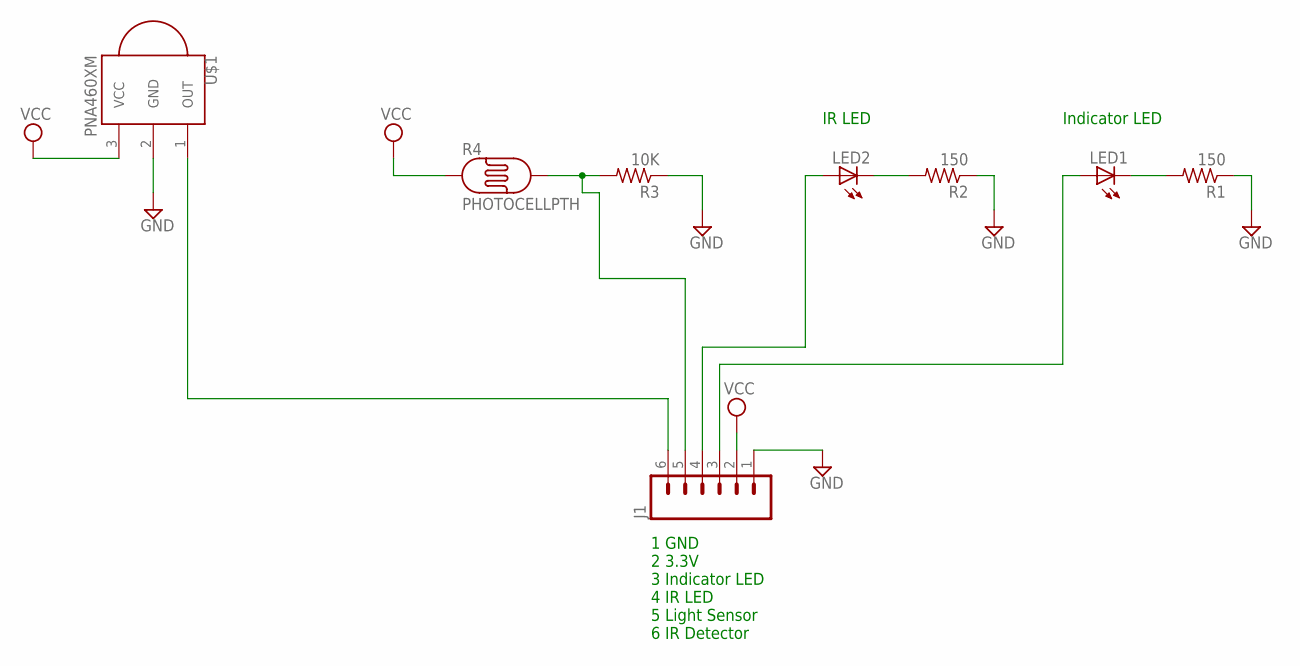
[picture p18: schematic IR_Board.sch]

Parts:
J1: M06LONGPADS; 1X06_LONGPADS
LED1: LED3MM
LED2: LED5MM
R1, R2: 150; M0805
R3: 10K; M0805
R4: PHOTOCELLPTH; PHOTOCELL
U$1: PNA460XM

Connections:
GND: J1.1, R1.1, R2.1, R3.1, U$1.2 (GND)
unnamed: J1.5, R3.2, R4.2
unnamed: LED2.K (C), R2.2
unnamed: LED1.K (C), R1.2
unnamed: J1.3, LED1.A
unnamed: J1.4, LED2.A
unnamed: J1.6, U$1.1 (OUT)
VCC: J1.2, R4.1, U$1.3 (VCC)

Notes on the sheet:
IR LED
Indicator LED
1 GND 2 3.3V 3 Indicator LED 4 IR LED 5 Light Sensor 6 IR Detector

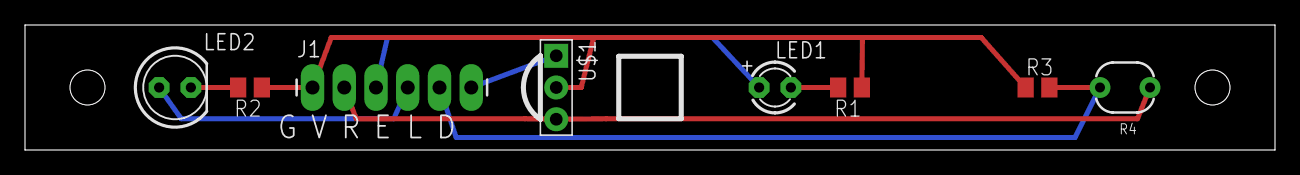
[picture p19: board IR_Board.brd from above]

Board: 2 copper layers, 100.0 x 10.0 mm, 8 parts (0 on the bottom side), 8 nets.

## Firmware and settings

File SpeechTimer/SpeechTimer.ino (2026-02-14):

/*
 SpeechTimer.ino

  AUTHOR: Richard Teel
  DATE: 15 October 2023
  HW TESTED: Raspberry Pi Pico W

  Speech Timer for Toastmasters Club or any event that needs to display a timer with minutes and seconds.
  ** Features **
    - Clock is displayed if there is an internet connection and the timer is not running.
    - Web interface for operation and configuration.
    - IR Remote for simpler control with speech timer presets of:
      - 1 to 2 minutes for Table Topics
      - 5 to 7 minutes for Speech (default)
      - 2 to 3 minutes for Evaluation
      - Ability to manually set a timer
    - Timer digits change color based on timer settings
      - Digits are white when started
      - Digits are green when the minimum time is reached
      - Digits are yellow when the halfway between the minimum and maximum times
      - Digits are red when the maximum time is reached and stay red
  
  ** Issues/Future Improvements **
  These items are known and planed to be worked on in the future but there is no guarantee that any of 
  them will be addressed.
    - When starting, it may take a minute or longer before the timer function is available. This is due 
      to the time it takes to attempt to set up a Wi-Fi connection. Startup may happen as quickly as 10 
      seconds but may last up to 2 minutes.
    - An auxiliary clock display is planned to allow the same information to be displayed with one 
      positioned for the speaker and the other for the timer/audience.
  
  ** HW Device Connection on Raspberry Pi Pico W **
    Pin GPIO  Device  Device Pin/Function
    6   GP4   OLED      SDA
    7   GP5   OLED      SCK
    20  GP15  Indicator LED
    21  GP16  SD Card   MISO
    22  GP17  SD Card   CS
    24  GP18  SD Card   SCK
    25  GP19  SD Card   MOSI
    26  GP20  SD Card   CD
    29  GP22  IR LED
    31  GP26  IR Remote Signal
    32  GP27  Light Detector (CdS Photoresistor)
    34  GP28  NeoPixels Data

  Power
    NeoPixels - GND and VBUS (Pin 40)
    SD Card   - GND and 3V (Pin 36)
    OLED      - GND and 3V (Pin 36)
    IR Remote - GND and 3V (Pin 36)

  Other References
  - Running code on both threads of the RP2040: https://arduino-pico.readthedocs.io/en/latest/multicore.html
  - Explaination of mutex and semaphore: https://forum.arduino.cc/t/mutex-and-semaphore/1078290/4
  - Example with RTOS semaphore: https://github.com/garyexplains/examples/blob/master/Dual_Core_for_RP2040_ESP32_ESP32-S3/unified_dual_core_with_lock/unified_dual_core_with_lock.ino
    Video explaining code is at: https://youtu.be/w5YigjvSaF4?si=kgyumJVpnzHefH1o
  - BLE with WiFi and FreeRTOS on Raspberry Pi Pico-W: https://mcuoneclipse.com/2023/03/19/ble-with-wifi-and-freertos-on-raspberry-pi-pico-w/
*/

#define FILE_NAME "[SpeechTimer.ino]"

/*****************************************************************************
 *                               Project Files                               *
 *****************************************************************************/
// Include Defines.h FIRST to set __FREERTOS 1 before FreeRTOS headers
#include "Defines.h"   // Pin definitions, programming mode, and debug flag (defines __FREERTOS)
#include "DbgPrint.h"  // Serial helpers

/*****************************************************************************
 *                              FreeRTOS Setup                               *
 *****************************************************************************/
// __FREERTOS 1 is defined in Defines.h for RP2040
#if !defined(ESP_PLATFORM) && !defined(ARDUINO_ARCH_MBED_RP2040) && !defined(ARDUINO_ARCH_RP2040)
#pragma message("Unsupported platform")
#endif

// ESP32:
#if defined(ESP_PLATFORM)
TaskHandle_t task_loop1;
void esploop1(void *pvParameters) {
  setup1();

  for (;;)
    loop1();
}
#endif

#if defined(ARDUINO_ARCH_MBED_RP2040) || defined(ARDUINO_ARCH_RP2040)
#include <FreeRTOS.h>
#include <task.h>
#include <semphr.h>
#define xPortGetCoreID get_core_num
#endif

/*****************************************************************************
 *                               Include Files                               *
 *****************************************************************************/
// #include <Dictionary.h>  // Not currently used

/*****************************************************************************
 *                               Additional Project Files                    *
 *****************************************************************************/
#include "Clk_Output.h"
#include "Clk_Remote.h"
#include "config.h"      // Structures for the configuration file
#include "Clk_SdCard.h"  // Higher level SD Card functions
#include "Clk_Wifi.h"    // Higher level Wi-Fi functions
#include "Clk_Rtc.h"
#include "StructsAndEnums.h"

/*****************************************************************************
 *                               Other Includes                              *
 *****************************************************************************/
// #include <map>

/*****************************************************************************
 *                                 DICTIONARY                                *
 *****************************************************************************/
/*
  Dictionary Keys
    - cpu_freq
    - cpu_temp_c
    - cpu_temp_f
    - cpu_uid
    - cpu_voltage
    - max_time
    - mem_free
    - mem_percent_free
    - mem_percent_used
    = mem_total
    - mem_used
    - min_time
    - neo_blue
    - neo_green
    - neo_red
    - reset_reason
    - selected_tab
    - server_folder
    - timer_button_text
    - visits
*/
// Dictionary* dict = new Dictionary(20);

/*****************************************************************************
 *                                  GLOBALS                                  *
 *****************************************************************************/
// Flags to make certain that required initialization is complete before tasks start
bool setup_complete = false;

// WiFi global settings
char last_ipaddress[16] = "";
WiFiMode_t last_WiFiMode = WIFI_OFF;

// Config global settings
unsigned long configLoadMillis = 0;
unsigned long last_configLoadMillis = 0;

// Module Objects
Clk_SdCard clockSdCard = Clk_SdCard();
Clk_Wifi clockWifi = Clk_Wifi();
Clk_Output clockOutput = Clk_Output(&clockSdCard);
Clk_Rtc clockRtc = Clk_Rtc(&clockSdCard, &clockWifi);
Clk_Remote clockRemote = Clk_Remote();
ClockMode last_clockMode = ClockMode::Clock;

/*****************************************************************************
 *                                 LOG FILES                                 *
 *****************************************************************************/
char logDebug[] = "/logs/debug.log";
char logDebugArchive[] = "/logs/debug_1.log";

/*****************************************************************************
 *                                DEBUG LEVEL                                *
 *****************************************************************************/
DebugLevels debugLevel = DebugLevels::Verbose;
// DebugLevels debugLevel = DebugLevels::Info;
// DebugLevels debugLevel = DebugLevels::Warning;
// DebugLevels debugLevel = DebugLevels::Error;

int waitLoopsToPrintTaskInfo = LOOPS_BEFORE_TASK_INFO_PRINT;

/*****************************************************************************
 *                                   QUEUES                                  *
 *****************************************************************************/
static const uint8_t log_queue_len = LOG_QUEUE_LENGTH;
static QueueHandle_t log_queue;

static const uint8_t remote_queue_len = REMOTE_QUEUE_LENGTH;
static QueueHandle_t remote_queue;

/*****************************************************************************
 *                                   MUTEX                                   *
 *****************************************************************************/
static SemaphoreHandle_t sdcard_mutex;
static SemaphoreHandle_t rtc_mutex;
static SemaphoreHandle_t config_mutex;
static SemaphoreHandle_t wifi_state_mutex;
static SemaphoreHandle_t display_state_mutex;

/*****************************************************************************
 *                               INO FUNCTIONS                               *
 *****************************************************************************/
void debugMessage(const char *message, const char *logfile = "", DebugLevels debug_level = DebugLevels::Info) {
  const char *errorlevel = debugLevelName[debug_level];
  if (debug_level < debugLevel) {
    return;
  }

  char timeStr[10] = "--:--";
  char msgBuffer[512];
  
  // Protect RTC access with mutex
  if (xSemaphoreTake(rtc_mutex, pdMS_TO_TICKS(MUTEX_TIMEOUT_MS)) == pdTRUE) {
    clockRtc.getTimeString(timeStr);
    xSemaphoreGive(rtc_mutex);
  }
  
  // Format the message
  sprintf(msgBuffer, "%s\t%s\t%s %s\t%d\t%d\t%d", timeStr, errorlevel, FILE_NAME, message, xPortGetCoreID(), rp2040.getFreeHeap(), uxTaskGetStackHighWaterMark(NULL));

  Log_Entry logEntry;
  strlcpy(logEntry.message, msgBuffer, sizeof(logEntry.message));
  strlcpy(logEntry.logfile, logfile, sizeof(logEntry.logfile));

  if (xQueueSend(log_queue, (void *)&logEntry, pdMS_TO_TICKS(QUEUE_SEND_TIMEOUT_MS)) != pdTRUE) {
    // Queue is full - try to make room by dropping oldest entry
    Log_Entry dummy;
    if (xQueueReceive(log_queue, &dummy, QUEUE_RECEIVE_NO_WAIT) == pdTRUE) {
      Dbg_printf("%s: %s debugMessage - Log Queue Full, dropped oldest entry\n", 
                 debugLevelName[DebugLevels::Warning], FILE_NAME);
      
      // Try to add new entry again
      if (xQueueSend(log_queue, (void *)&logEntry, QUEUE_RECEIVE_NO_WAIT) != pdTRUE) {
        // Still failed - critical error
        Dbg_printf("%s: %s debugMessage - CRITICAL: Failed to queue after making room:\n%s\n", 
                   debugLevelName[DebugLevels::Error], FILE_NAME, msgBuffer);
      }
    } else {
      // Couldn't even remove an entry - critical error
      Dbg_printf("%s: %s debugMessage - CRITICAL: Log Queue Full and cannot remove entries:\n%s\n", 
                 debugLevelName[DebugLevels::Error], FILE_NAME, msgBuffer);
    }
  }
}

/*****************************************************************************
 *                                   TASKS                                   *
 *****************************************************************************/
void checkRemote(void *param) {
  // Make certain that setup has completed
  while (!setup_complete) {
    vTaskDelay(pdMS_TO_TICKS(TASK_DELAY_SETUP_WAIT));
  }

  int loopCount = 0;
  char msgBuffer[255];

  UBaseType_t uxHighWaterMark;

  // Setup Indicator LED
  pinMode(PIN_LED_INDICATOR, OUTPUT);

  clockRemote.begin();

  while (1) {
    digitalWrite(PIN_LED_INDICATOR, LOW);

    char button = clockRemote.checkForButton();

    if (button != '\0') {
      if (xQueueSend(remote_queue, (void *)&button, pdMS_TO_TICKS(QUEUE_SEND_TIMEOUT_MS)) != pdTRUE) {
        // Queue is full - try to make room by dropping oldest button press
        char dummy;
        if (xQueueReceive(remote_queue, &dummy, QUEUE_RECEIVE_NO_WAIT) == pdTRUE) {
          // Successfully removed oldest, try to add new button
          if (xQueueSend(remote_queue, (void *)&button, QUEUE_RECEIVE_NO_WAIT) == pdTRUE) {
            digitalWrite(PIN_LED_INDICATOR, HIGH);
            debugMessage("checkRemote - Remote Queue Full, dropped oldest button", logDebug, DebugLevels::Warning);
          } else {
            debugMessage("checkRemote - CRITICAL: Remote Queue Full, button press lost", logDebug, DebugLevels::Error);
          }
        } else {
          debugMessage("checkRemote - CRITICAL: Remote Queue Full and cannot remove entries", logDebug, DebugLevels::Error);
        }
      } else {
        digitalWrite(PIN_LED_INDICATOR, HIGH);
      }
    }

    loopCount++;
    // Print message with stack usage once every ten loops
    if (loopCount > waitLoopsToPrintTaskInfo) {
      debugMessage("checkRemote");
      loopCount = 0;
    }
    vTaskDelay(pdMS_TO_TICKS(TASK_DELAY_REMOTE_CHECK));
  }
}

void checkSdCard(void *param) {
  // Make certain that setup has completed
  while (!setup_complete) {
    vTaskDelay(pdMS_TO_TICKS(TASK_DELAY_SETUP_WAIT));
  }

  int loopCount = 0;
  Log_Entry item;

  while (1) {
    bool cardPresent = false;
    unsigned long currentConfigLoadMillis = 0;
    
    if (xSemaphoreTake(sdcard_mutex, pdMS_TO_TICKS(MUTEX_TIMEOUT_MS)) == pdTRUE) {
      cardPresent = clockSdCard.isCardPresent();
      xSemaphoreGive(sdcard_mutex);
    } else {
      continue;
    }
    
    // Protect config state variables with mutex
    if (xSemaphoreTake(config_mutex, pdMS_TO_TICKS(MUTEX_TIMEOUT_MS)) == pdTRUE) {
      if (!cardPresent) {
        last_configLoadMillis = 0;
        configLoadMillis = 0;
      } else if (configLoadMillis == 0) {
        configLoadMillis = millis();
      }
      currentConfigLoadMillis = configLoadMillis;
      xSemaphoreGive(config_mutex);
    } else {
      continue;
    }

    // Check if there are log entries to write to the SD Card
    bool writeToFile = false;
    while (xQueueReceive(log_queue, (void *)&item, QUEUE_RECEIVE_NO_WAIT) == pdTRUE) {
      if (currentConfigLoadMillis != 0 && strlen(item.logfile) > 0) {
        writeToFile = true;
      }

      if (writeToFile) {
        // Retry logic to prevent log entry loss
        constexpr uint8_t MAX_RETRIES = MAX_SDCARD_WRITE_RETRIES;
        uint8_t retries = 0;
        bool writtenSuccessfully = false;
        
        while (retries < MAX_RETRIES) {
          if (xSemaphoreTake(sdcard_mutex, pdMS_TO_TICKS(MUTEX_TIMEOUT_SHORT_MS)) == pdTRUE) {
            clockSdCard.writeLogEntry(item.logfile, item.message);
            xSemaphoreGive(sdcard_mutex);
            writtenSuccessfully = true;
            break;
          }
          retries++;
          if (retries < MAX_RETRIES) {
            vTaskDelay(pdMS_TO_TICKS(RETRY_DELAY_MS));  // Brief delay before retry
          }
        }
        
        if (!writtenSuccessfully) {
          // Failed after all retries - try to preserve the message by re-queuing
          Dbg_printf("%s: %s checkSdCard - Failed to write log entry after %d retries. Attempting to re-queue.\n", 
                     debugLevelName[DebugLevels::Error], FILE_NAME, MAX_RETRIES);
          
          // Try to put the item back at the front of the queue
          if (xQueueSendToFront(log_queue, (void *)&item, QUEUE_RECEIVE_NO_WAIT) != pdTRUE) {
            Dbg_printf("%s: %s checkSdCard - CRITICAL: Could not re-queue log entry. Message lost:\n%s\n", 
                       debugLevelName[DebugLevels::Error], FILE_NAME, item.message);
          }
          writeToFile = false;
        }
      }

      if (!writeToFile || debugLevel == DebugLevels::Verbose) {
        Dbg_printf("%s\n", item.message);
      }
    }

    loopCount++;
    // Print message with stack usage once every ten loops
    if (loopCount > waitLoopsToPrintTaskInfo) {
      debugMessage("checkSdCard");
      loopCount = 0;
    }
    vTaskDelay(pdMS_TO_TICKS(TASK_DELAY_SDCARD_CHECK));
  }
}


// void checkWiFi(void *param) {
void checkWiFi() {
  // Make certain that setup has completed
  while (!setup_complete) {
    vTaskDelay(pdMS_TO_TICKS(TASK_DELAY_SETUP_WAIT));
  }

  int loopCount = 0;
  char msgBuffer[255];

  while (1) {
    // Protect config state variables with mutex
    unsigned long currentConfigLoadMillis = 0;
    unsigned long currentLastConfigLoadMillis = 0;
    
    if (xSemaphoreTake(config_mutex, pdMS_TO_TICKS(MUTEX_TIMEOUT_MS)) == pdTRUE) {
      currentConfigLoadMillis = configLoadMillis;
      currentLastConfigLoadMillis = last_configLoadMillis;
      xSemaphoreGive(config_mutex);
    }
    
    // If the SD Card was inserted/reinserted, use the new configuration to connect to the Wi-Fi AP
    if (currentConfigLoadMillis != currentLastConfigLoadMillis) {
      debugMessage("checkWiFi - START: Restart Wi-Fi with new Config", logDebug);

      unsigned long startConnect = millis();
      clockWifi.begin(&clockSdCard.sdCardConfig);
      if (clockWifi.hasIpAddress()) {
        sprintf(msgBuffer, "checkWiFi - Connected in %d ms", millis() - startConnect);
      } else {
        sprintf(msgBuffer, "checkWiFi - Failed to connect in %d ms", millis() - startConnect);
      }
      debugMessage(msgBuffer, logDebug);
      debugMessage("checkWiFi - Wi-Fi Begin Completed", logDebug);
      
      // Update last_configLoadMillis with mutex protection
      if (xSemaphoreTake(config_mutex, pdMS_TO_TICKS(MUTEX_TIMEOUT_MS)) == pdTRUE) {
        last_configLoadMillis = configLoadMillis;
        xSemaphoreGive(config_mutex);
      }
      
      debugMessage("checkWiFi - END: Restart Wi-Fi with new Config", logDebug);
    }

    // Set the IP Address property
    bool hasIp = clockWifi.hasIpAddress();

    // Protect WiFi state variables with mutex
    if (xSemaphoreTake(wifi_state_mutex, pdMS_TO_TICKS(MUTEX_TIMEOUT_MS)) == pdTRUE) {
      // If the IP Address has changed, print the IP Address
      if (strcmp(last_ipaddress, clockWifi.ipAddress) != 0) {
        debugMessage("checkWiFi - START: Update IP Address", logDebug);
        strcpy(last_ipaddress, clockWifi.ipAddress);
        clockOutput.updateIpAddress(last_ipaddress);
        sprintf(msgBuffer, "checkWiFi - IP Address has changed to %s", last_ipaddress);
        debugMessage(msgBuffer, logDebug);
        debugMessage("checkWiFi - END: Update IP Address", logDebug);
      }

      // If the Wi-Fi Mode has changed, print debug message
      if (last_WiFiMode != clockWifi.wifiMode) {
        last_WiFiMode = clockWifi.wifiMode;
        sprintf(msgBuffer, "checkWiFi - Wi-Fi has changed to %s", wifiModeName[last_WiFiMode]);
        debugMessage(msgBuffer, logDebug);
        // Set NeoPixels to green when WiFi connects (waiting for time sync)
        if (clockWifi.wifiMode == WIFI_STA && clockWifi.isWiFiConnected()) {
          clockOutput.setWiFiConnectedWaitingForTime();
        }
      }
      
      xSemaphoreGive(wifi_state_mutex);
    }

    char currentTime[10] = "--:--";
    
    // Protect RTC access with mutex
    if (xSemaphoreTake(rtc_mutex, pdMS_TO_TICKS(MUTEX_TIMEOUT_MS)) == pdTRUE) {
      if (hasIp && !clockRtc.timeIsSet()) {
        clockRtc.getInternetTime();
        if (clockRtc.timeIsSet()) {
          clockRtc.getTimeString(currentTime);

          sprintf(msgBuffer, "checkWiFi - Current time is: %s", currentTime);
          debugMessage(msgBuffer, logDebug);
        }
      }
      xSemaphoreGive(rtc_mutex);
    }

    loopCount++;
    // Print message with stack usage once every ten loops
    if (loopCount > waitLoopsToPrintTaskInfo) {
      debugMessage("checkWiFi");
      loopCount = 0;
    }
    
    // Adaptive delay: Fast when connecting, slow when stable
    // This improves responsiveness during connection while saving CPU when stable
    TickType_t delay = hasIp ? 
                       pdMS_TO_TICKS(TASK_DELAY_WIFI_CHECK_STABLE) :   // 1000ms when connected
                       pdMS_TO_TICKS(TASK_DELAY_WIFI_CHECK_UNSTABLE); // 250ms when connecting
    vTaskDelay(delay);
  }
}

/*****************************************************************************
 *                           REMOTE INPUT HANDLERS                           *
 *****************************************************************************/
void handleTimerDigitInput(char digit) {
  // Optimize: Use direct arithmetic instead of sprintf+atoi
  // Shift digits left and append new digit: 12 + '3' = 123
  int digitValue = digit - '0';  // Convert char to int
  
  if (clockOutput.clockMode == ClockMode::TimerSetMin) {
    int minVal = clockOutput.timerSetMin();
    minVal = (minVal * 10 + digitValue) % 100;  // Append digit, keep in valid range
    clockOutput.timerSetMin(minVal);
  } else if (clockOutput.clockMode == ClockMode::TimerSetMax) {
    int maxVal = clockOutput.timerSetMax();
    maxVal = (maxVal * 10 + digitValue) % 100;  // Append digit, keep in valid range
    clockOutput.timerSetMax(maxVal);
  }
}

void handleHashButton() {
  if (clockOutput.clockMode == ClockMode::Clock) {
    clockOutput.clockMode = ClockMode::TimerReady;
    clockOutput.timerNext(false);
  } else if (clockOutput.clockMode == ClockMode::TimerReady || 
             clockOutput.clockMode == ClockMode::TimerSetMin || 
             clockOutput.clockMode == ClockMode::TimerSetMax) {
    clockOutput.timerNext();
  }
}

void handleNavigationInput(char direction) {
  if (direction == 'L' && clockOutput.clockMode == ClockMode::TimerSetMax) {
    clockOutput.clockMode = ClockMode::TimerSetMin;
  } else if (direction == 'R' && clockOutput.clockMode == ClockMode::TimerSetMin) {
    clockOutput.clockMode = ClockMode::TimerSetMax;
  }
}

void handleOkButton() {
  if (clockOutput.clockMode == ClockMode::TimerReady) {
    clockOutput.clockMode = ClockMode::TimerRun;
  } else if (clockOutput.clockMode == ClockMode::TimerRun) {
    clockOutput.clockMode = ClockMode::TimerStop;
  } else if (clockOutput.clockMode == ClockMode::TimerStop) {
    clockOutput.clockMode = ClockMode::TimerReady;
  }
}
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
void loop() {
  // The core written by Earle F. Philhower, III, requires that the Wi-Fi be
  // accessed from Core 0, therefore it needs to run in the loop.
  checkWiFi();
}

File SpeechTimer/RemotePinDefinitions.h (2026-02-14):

/*
 *  PinDefinitionsAndMore.h
 *
 *  Contains pin definitions for IRremote examples for various platforms
 *  as well as definitions for feedback LED and tone() and includes
 *
 *  Copyright (C) 2021-2023  Armin Joachimsmeyer
 *  armin.joachimsmeyer@gmail.com
 *
 *  This file is part of IRremote https://github.com/Arduino-IRremote/Arduino-IRremote.
 *
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
 */

/*
 * Pin mapping table for different platforms
 *
 * Platform     IR input    IR output   Tone      Core/Pin schema
 * --------------------------------------------------------------
 * DEFAULT/AVR  2           3           4         Arduino
 * ATtinyX5     0|PB0       4|PB4       3|PB3     ATTinyCore
 * ATtiny167    3|PA3       2|PA2       7|PA7     ATTinyCore
 * ATtiny167    9|PA3       8|PA2       5|PA7     Digispark original core
 * ATtiny84      |PB2        |PA4        |PA3     ATTinyCore
 * ATtiny88     3|PD3       4|PD4       9|PB1     ATTinyCore
 * ATtiny3217  18|PA1      19|PA2      20|PA3     MegaTinyCore
 * ATtiny1604   2           3|PA5       %
 * ATtiny816   14|PA1      16|PA3       1|PA5     MegaTinyCore
 * ATtiny1614   8|PA1      10|PA3       1|PA5     MegaTinyCore
 * SAMD21       3           4           5
 * ESP8266      14|D5       12|D6       %
 * ESP32        15          4           27
 * BluePill     PA6         PA7         PA3
 * APOLLO3      11          12          5
 * RP2040       3|GPIO15    4|GPIO16    5|GPIO17
 */
//#define _IR_MEASURE_TIMING // For debugging purposes.

#if defined(__AVR__)
#if defined(__AVR_ATtiny25__) || defined(__AVR_ATtiny45__) || defined(__AVR_ATtiny85__) // Digispark board. For use with ATTinyCore.
#include "ATtinySerialOut.hpp" // TX is at pin 2 - Available as Arduino library "ATtinySerialOut". Saves 700 bytes program memory and 70 bytes RAM for ATtinyCore.
#define IR_RECEIVE_PIN  PIN_PB0
#define IR_SEND_PIN     PIN_PB4 // Pin 2 is serial output with ATtinySerialOut. Pin 1 is internal LED and Pin3 is USB+ with pullup on Digispark board.
#define TONE_PIN        PIN_PB3
#define _IR_TIMING_TEST_PIN PIN_PB3

#  elif defined(__AVR_ATtiny87__) || defined(__AVR_ATtiny167__) // Digispark pro board
#include "ATtinySerialOut.hpp" // Available as Arduino library "ATtinySerialOut"
// For ATtiny167 Pins PB6 and PA3 are usable as interrupt source.
#  if defined(ARDUINO_AVR_DIGISPARKPRO)
// For use with Digispark original core
#define IR_RECEIVE_PIN   9 // PA3 - on Digispark board labeled as pin 9
//#define IR_RECEIVE_PIN  14 // PB6 / INT0 is connected to USB+ on DigisparkPro boards
#define IR_SEND_PIN      8 // PA2 - on Digispark board labeled as pin 8
#define TONE_PIN         5 // PA7 - on Digispark board labeled as pin 5
#define _IR_TIMING_TEST_PIN 10 // PA4
#  else
// For use with ATTinyCore
#define IR_RECEIVE_PIN  PIN_PA3 // On Digispark board labeled as pin 9 - INT0 is connected to USB+ on DigisparkPro boards
#define IR_SEND_PIN     PIN_PA2 // On Digispark board labeled as pin 8
#define TONE_PIN        PIN_PA7 // On Digispark board labeled as pin 5
#  endif

#  elif defined(__AVR_ATtiny84__) // For use with ATTinyCore
#include "ATtinySerialOut.hpp" // Available as Arduino library "ATtinySerialOut". Saves 128 bytes program memory.
#define IR_RECEIVE_PIN   PIN_PB2 // INT0
#define IR_SEND_PIN      PIN_PA4
#define TONE_PIN         PIN_PA3
#define _IR_TIMING_TEST_PIN PIN_PA5

#  elif defined(__AVR_ATtiny88__) // MH-ET Tiny88 board. For use with ATTinyCore.
#include "ATtinySerialOut.hpp" // Available as Arduino library "ATtinySerialOut". Saves 128 bytes program memory.
// Pin 6 is TX, pin 7 is RX
#define IR_RECEIVE_PIN   PIN_PD3 // 3 - INT1
#define IR_SEND_PIN      PIN_PD4 // 4
#define TONE_PIN         PIN_PB1 // 9
#define _IR_TIMING_TEST_PIN PIN_PB0 // 8

#  elif defined(__AVR_ATtiny1616__)  || defined(__AVR_ATtiny3216__) || defined(__AVR_ATtiny3217__) // For use with megaTinyCore
// Tiny Core Dev board
// https://www.tindie.com/products/xkimi/tiny-core-16-dev-board-attiny1616/
// https://www.tindie.com/products/xkimi/tiny-core-32-dev-board-attiny3217/
#define IR_RECEIVE_PIN   PIN_PA1 // use 18 for TinyCore32
#define IR_SEND_PIN      PIN_PA2 // 19
#define TONE_PIN         PIN_PA3 // 20
#define APPLICATION_PIN  PIN_PA0 // 0
#undef LED_BUILTIN               // No LED available on the TinyCore 32 board, take the one on the programming board which is connected to the DAC output
#define LED_BUILTIN      PIN_PA6 // use 2 for TinyCore32

#  elif defined(__AVR_ATtiny816__) // For use with megaTinyCore
#define IR_RECEIVE_PIN  PIN_PA1 // 14
#define IR_SEND_PIN     PIN_PA1 // 16
#define TONE_PIN        PIN_PA5 // 1
#define APPLICATION_PIN PIN_PA4 // 0
#undef LED_BUILTIN              // No LED available, take the one which is connected to the DAC output
#define LED_BUILTIN     PIN_PB5 // 4

#  elif defined(__AVR_ATtiny1614__) // For use with megaTinyCore
#define IR_RECEIVE_PIN   PIN_PA1 // 8
#define IR_SEND_PIN      PIN_PA3 // 10
#define TONE_PIN         PIN_PA5 // 1
#define APPLICATION_PIN  PIN_PA4 // 0
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

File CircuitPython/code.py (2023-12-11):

import time

import helper_clock
import helper_display
import helper_print
import helper_rtc
import helper_server
import helper_timer
import helper_wifi
import helper_sd_card

import board
import pulseio
import adafruit_irremote

debug = False
last_neopixel_colors = helper_clock.neopixel_colors


def set_time():
    global time_set

    timeset_status = helper_rtc.Set_RTC_Time(debug)
    time_set = timeset_status["successful"]
    helper_print.debug_msg(debug, timeset_status)


# ***** SETUP *****
time_set = False
helper_display.setup_display()
helper_sd_card.sd_card_setup(debug)
helper_wifi.setup_wifi(debug)


helper_display.update_display(1, f"IP: {helper_wifi.wifi_ip()}")
helper_display.update_display(2, "Current Time")
helper_display.update_display(3, "")

last_update = time.monotonic()  # Time in seconds since power on

helper_clock.clock_setup()

set_time()

# helper_clock.update_clock_display(helper_rtc.str_time())

server_is_available = helper_server.server_setup(debug)

# ***** MAIN LOOP *****
last_function = helper_server.function
last_test_step = 0
last_time_display = ""
current_time_display = ""
last_test_update = time.monotonic()  # Time in seconds since power on

# IR Remote Setup
pulsein = pulseio.PulseIn(board.A0, maxlen=120, idle_state=True)
decoder = adafruit_irremote.NonblockingGenericDecode(pulsein)
t0 = next_heartbeat = time.monotonic()

def read_ir():
    global next_heartbeat

    for message in decoder.read():
        print(f"t={time.monotonic() - t0:.3} New Message")
        print("Heard", len(message.pulses), "Pulses:", message.pulses)
        if isinstance(message, adafruit_irremote.IRMessage):
            print("Decoded:", message.code)
        elif isinstance(message, adafruit_irremote.NECRepeatIRMessage):
            print("NEC repeat!")
        elif isinstance(message, adafruit_irremote.UnparseableIRMessage):
            print("Failed to decode", message.reason)
        print("----------------------------")

    # This heartbeat confirms that we are not blocked somewhere above.
    t = time.monotonic()
    if t > next_heartbeat:
        # print(f"t={time.monotonic() - t0:.3} Heartbeat")
        next_heartbeat = t + 0.1

while True:
    read_ir()
    if time.monotonic() - last_update >= 0.1:
        if not time_set:
            set_time()

        helper_display.update_display(1, f"IP: {helper_wifi.wifi_ip()}")

        last_update = time.monotonic()

        if time_set:
            helper_display.update_display(3, helper_rtc.str_time())

        if last_function == helper_server.FUNCTION_SPEECH_TIMER:
            timer = helper_timer.get_remaining_time()
            last_colors = helper_clock.neopixel_colors
            helper_clock.neopixel_colors = timer["color"]
            current_time_display = timer["timestring"]
        elif last_function == helper_server.FUNCTION_CLOCK:
            current_time_display = "-- --"

            if time_set:
                current_time_display = helper_rtc.str_time()
        elif last_function == helper_server.FUNCTION_TEST:
            if time.monotonic() - last_test_update >= 1.0:
                last_test_update = time.monotonic()
                current_time_display = "88:88"

                if last_test_step > 6:
                    last_test_step = 0

                if last_test_step == 0:
                    helper_clock.neopixel_colors = [128, 0, 0]
                elif last_test_step == 1:
                    helper_clock.neopixel_colors = [0, 128, 0]
                elif last_test_step == 2:
                    helper_clock.neopixel_colors = [0, 0, 128]
                elif last_test_step == 3:
                    helper_clock.neopixel_colors = [0, 128, 128]
                elif last_test_step == 4:
                    helper_clock.neopixel_colors = [128, 0, 128]
                elif last_test_step == 5:
                    helper_clock.neopixel_colors = [128, 128, 0]
                elif last_test_step == 6:
                    helper_clock.neopixel_colors = [128, 128, 128]

                last_test_step = last_test_step + 1
                helper_clock.update_clock_display(current_time_display)

    if current_time_display != last_time_display:
        helper_clock.update_clock_display(current_time_display)
        last_time_display = current_time_display

    if last_function != helper_server.function:
        last_function = helper_server.function
        if last_function == helper_server.FUNCTION_SPEECH_TIMER:
            last_neopixel_colors = helper_clock.neopixel_colors
            helper_timer.timer_min = helper_server.speech_timer_min
            helper_timer.timer_max = helper_server.speech_timer_max
            helper_timer.start_timer()
        elif last_function == helper_server.FUNCTION_TEST:
            last_test_step = 0

    #  poll the server for incoming/outgoing requests
    if server_is_available:
        try:
            # Process any waiting requests
            poll_result = helper_server.server.poll()

            if poll_result == helper_server.SERVER_REQUEST_HANDLED_RESPONSE_SENT:
                # Do something only after handling a request
                pass

        except BrokenPipeError as e:
            helper_print.debug_msg(True, f"Exception: {e}")
            server_is_available = helper_server.server_setup(debug)
            continue

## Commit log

2023-09-16 Initial code with CircuitPython project
2023-09-23 Adding sample test output
2023-09-28 - Turned off Test and Debug - Replaced Serial.print statements with debug D_print statements - Found an error with the WiFi library, which requires that Serial.begin is called. Edited code to call Se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
    [SpeechTimer.ino]
2023-09-30 Fixed a problem with disabling the use of Serial.print, which caused WiFi connection code to be skipped. It appears that milllis() may reset to zero only when Serial.begin() is called. If it is not c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
    [SpeechTimer.ino]
2023-10-14 - Adding PCB and Schematic - Adding latest software changes
    [IR_Board.brd, IR_Board.sch, LEDs.brd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]
2023-12-11 Arduino C++ version working, but without web client
    [Book1.xlsx, Book2 (Holes & Colors).xlsx, Case.skp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]

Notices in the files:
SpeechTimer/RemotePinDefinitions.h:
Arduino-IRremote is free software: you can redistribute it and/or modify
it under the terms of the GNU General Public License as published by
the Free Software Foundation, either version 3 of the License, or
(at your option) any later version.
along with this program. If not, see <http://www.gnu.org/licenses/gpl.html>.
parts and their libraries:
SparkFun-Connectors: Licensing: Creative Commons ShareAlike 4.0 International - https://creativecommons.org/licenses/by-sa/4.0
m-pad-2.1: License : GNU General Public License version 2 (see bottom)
